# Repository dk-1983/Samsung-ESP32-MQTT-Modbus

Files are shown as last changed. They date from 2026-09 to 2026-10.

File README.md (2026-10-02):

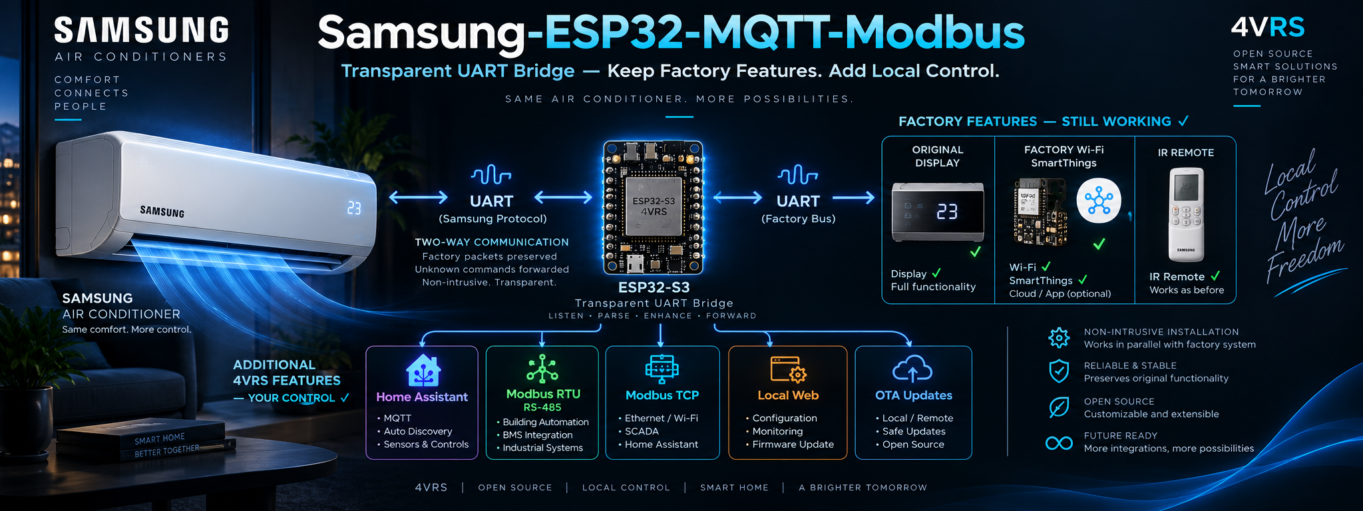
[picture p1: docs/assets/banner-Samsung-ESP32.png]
Samsung-ESP32-MQTT-Modbus — 4VRS


# Samsung-ESP32-MQTT-Modbus — 1.0.2

[Русский](README_RU.md)

**[Download stable v1.0.2](https://github.com/dk-1983/Samsung-ESP32-MQTT-Modbus/releases/tag/v1.0.2)** — ready-made OTA binary for already provisioned ESP32-S3 N16R8 controllers. Not a first-install image for a blank board.

**Keep Samsung's factory features and add 4VRS control.**

Samsung-ESP32-MQTT-Modbus is an ESP32-S3 expansion controller with a transparent
inline UART bridge between the AC motherboard and its original display/Wi-Fi board.
The architecture is designed to preserve the full factory functionality: the
original boards keep communicating, while the IR remote, display and Samsung
SmartThings coexist with the additional 4VRS interfaces.

Our 4VRS polling and command dispatcher runs on the ESP32. It tracks factory
transactions, selects an idle window for each own request and coordinates access
from the web controls, MQTT and Modbus to the shared UART bus. A command is confirmed
only by reading the actual AC state. Unknown factory packets are forwarded unchanged,
so forwarding is not limited to the commands implemented by our firmware.

Additional interfaces:

- **Wi-Fi:** local network connectivity and OTA firmware updates.
- **HTTP Remote:** a local web remote and HTTP API for control over the network.
- **MQTT / Home Assistant Discovery:** automatic device and entity discovery. No custom Samsung/4VRS integration, HACS package or manual entity configuration is required; use the standard MQTT integration with your broker.
- **Modbus RTU / TCP:** RS485 and network automation integration.

Local 4VRS interfaces do not require Samsung's cloud. Factory SmartThings retains
its own connection through the original Wi-Fi module. Display, IR remote and
SmartThings control have been checked with the bridge on AR24BSFCMWKNER;
exhaustive validation of every factory function is still pending.

Repository: [dk-1983/Samsung-ESP32-MQTT-Modbus](https://github.com/dk-1983/Samsung-ESP32-MQTT-Modbus).
See [bridge wiring and limitations](docs/UART_BRIDGE.md).

Home Assistant is optional: connect the controller to your own MQTT broker and automation server. See [topics, commands, states and the complete Discovery-based inventory](docs/HOME_ASSISTANT.md#own-mqtt-broker-without-home-assistant).

[Complete Modbus register list with Samsung / 4VRS separation](docs/MODBUS.md): the factory indoor-unit range ends at **2449**, and our extensions begin at **2450**.

[Electrical schematic, wiring and PCB component libraries](hardware/README.md).

## Home Assistant via Modbus Devices

**[Modbus Devices](https://github.com/dk-1983/Modbus_Devices#4vrs) includes a dedicated profile for this controller: manufacturer `4VRS`, model `Samsung-ESP32-Modbus`.**

Connect through Modbus TCP over Wi-Fi or Modbus RTU over RS485 to get climate
control, the full fan/swing/preset controls, confirmed writes, and link and command
diagnostics in Home Assistant. The profile uses our extended register map;
you do not need to enter each register manually. MQTT is not required for this option.

1. Install [Modbus Devices](https://github.com/dk-1983/Modbus_Devices#installation) in Home Assistant.
2. Open `/modbus` on the controller and enable TCP or RTU.
3. Add the device using **4VRS → Samsung-ESP32-Modbus** and your connection settings.
   For direct TCP, use the controller IP, port **502** and configured Unit ID (default **1**).
   For RTU, match the controller's serial settings (default **9600 8E1**).

Select the **4VRS** profile for this device; the Samsung **MIM-B19N(T)** profile
is for the factory adapter. For MQTT-based setup, use Home Assistant's standard
MQTT integration with Discovery as described above.

## Electrical schematic

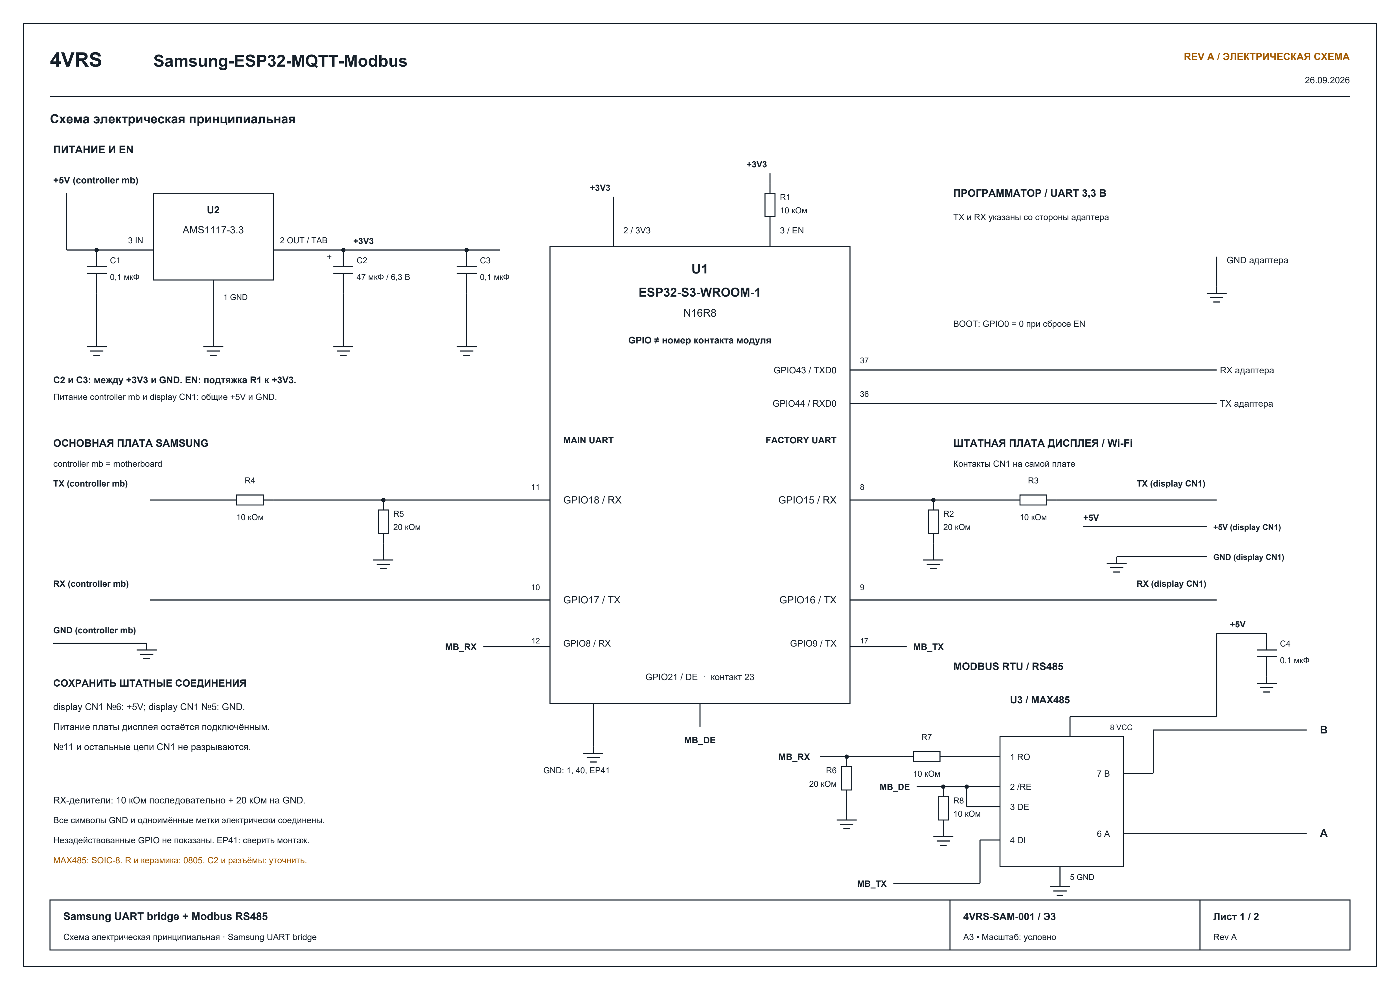
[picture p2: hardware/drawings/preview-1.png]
Samsung ESP32-S3 inline UART bridge and Modbus RS485 schematic


Motherboard UART: **RX18 / TX17**. Original display/Wi-Fi board: **RX15 / TX16**.
Modbus RS485: **RX8 / TX9 / DE21**. Numbers are ESP32 GPIOs, not module pad numbers.
Both Samsung boards retain their +5 V and common ground connections.

[Open full-resolution schematic](hardware/drawings/preview-1.png) · [Vector PDF](hardware/drawings/Samsung_transparency_bridge_revA-review.pdf) · [PCB component libraries](hardware/README.md)

## Controls and connections

The portal on port 80 links to controls, MQTT, Modbus and GitHub updates.
The Control link opens `/control`; advanced ESPHome controls remain on port 8080.
Both use `admin` and the same password stored on the device.

The main web interface on port 80 supports English and Russian. English is the
default; use the language selector to switch. Your browser remembers the selection.
This selector does not change the advanced ESPHome interface on port 8080.

- Independent persistent checkboxes for MQTT, Modbus RTU and Modbus TCP; all default off.
- Browser-configured MQTT broker/port/credentials/topic prefix and Home Assistant discovery.
- Browser-configured Modbus unit and RS485 baud rate; RTU defaults to 9600 8E1, TCP port 502.
- GitHub automatic-install checkbox, manual check/install, progress, signed manifest,
  board profile, SHA256 validation and rollback.
- Local ESPHome OTA remains available and is coordinated with the GitHub worker.

[Management and releases](docs/MANAGEMENT.md) · [Full device register map](docs/MODBUS.md)
· [Home Assistant MQTT Discovery](docs/HOME_ASSISTANT.md)
· [Modbus register reference (Russian)](docs/MODBUS_REGISTERS_RU.md)
· [UART function reference](docs/FUNCTIONS_RU.md)

UART TX/RX GPIO17/18 uses 9600 8N1. RS485 TX/RX/DE uses 9/8/21.
The AC uses D0 UART, not native Modbus; ESP32 implements the external register map.
Core addresses follow MIM-B19N/B19NT; custom functions begin at 2450.

UART is enabled on every boot and can be disabled in the control page.
Saving MQTT settings reboots the controller after two seconds to apply credentials.
Feedback is never optimistic: acknowledgement is not proof of the requested AC state.

## Hardware compatibility, first installation and updates

**Inline bridge support starts with firmware 0.5.0. Versions 0.4.x use the earlier
non-bridge configuration; 0.5.0 and later target the bridge wiring shown here.**
From the ESP32 side, the AC motherboard uses RX GPIO18 / TX GPIO17, the original
Wi-Fi/display board uses RX GPIO15 / TX GPIO16, and Modbus RS485 uses
RX GPIO8 / TX GPIO9 / DE GPIO21.
Module pads 8/9 are GPIO15/16 (the bridge), not GPIO8/9 (Modbus).

Boards wired for the pre-0.5.0 non-bridge configuration are a different hardware
configuration.
Do not install the current OTA on them solely because their firmware version is
older. Check the wiring against the current schematic first; an OTA update does
not add the missing bridge connection or change the PCB routing.

- **Configured controller with the current bridge wiring:** update through
  `/updates`. A working 1.0.0 or 1.0.1 installation on this hardware can update
  directly; no intermediate version is required. Preserve NVS when updating.
- **New controller with the current bridge wiring:** build the current stable
  source with `./Build.ps1`, personal `secrets.yaml` and `public_release: "false"`
  (the default). Use `firmware.factory.bin` for initial USB/serial installation.
  First boot saves the web, local OTA and Samsung-Setup passwords in NVS.
  Connect to Samsung-Setup with your setup password and configure Wi-Fi at
  `http://192.168.4.1:8080/`. Subsequent updates can use public OTA releases.

The public `*-ota.bin` requires existing device credentials in NVS; it is not a
first-install image for a blank board. A ready-made public provisioning image is
not provided yet. Installing an old firmware version first is not required.
Hardware compatibility and initial credential provisioning are separate requirements.

## Build and validation

Run `./Build.ps1` to install pinned dependencies, run host tests and build, without
flashing. Local configuration is in `secrets.yaml`; neither it nor locally built
private binaries belong in a public release. OTA/factory binaries are under
`work/build/.pioenvs/samsung-s3`. On the first local build boot, credentials are saved
to NVS and survive subsequent public OTA updates.

The separate GitHub workflow prepares a clean public **OTA-only** artifact for
controllers with the current bridge wiring and provisioned credentials. Signing/publishing is a separate step.
See [release preparation](docs/MANAGEMENT.md#release).

Power, fan Low/Medium/High/Turbo and both swing axes were tested on the target AC
in earlier firmware. Persistent web settings, Modbus TCP and GitHub OTA have
been checked on a device, including credential/settings retention and boot confirmation.
Authenticated MQTT connectivity is verified. Physical RS485 and forced rollback still need testing.
Experimental legacy controls require per-function verification on this model.

[Protocol](docs/PROTOCOL.md) · [Attribution](THIRD_PARTY.md)

The `/about` page shows firmware, memory, connections and UART freshness.
Restart requires confirmation and preserves settings. It is rejected during OTA
or while an AC command is pending.

`/settings` independently changes web, local OTA and Samsung-Setup passwords.
Blank fields preserve current credentials; new values require confirmation.
Changes are stored in NVS and applied on restart. Forgotten-password recovery
is not implemented yet.

`/wifi` shows network, IP, MAC, signal and channel. `/wifi/reset` confirms a
Wi-Fi-only reset; reprovision through Samsung-Setup at `192.168.4.1:8080`.
Other settings are preserved.

[Overview, web controls and MQTT power commands (Russian)](docs/CONTROL_RU.md).

HVAC commands require fresh control permission and feedback. Requested power is
never restored automatically after a restart.

In inline mode the factory board owns startup and notification ACKs. Own writes
require fresh permission and feedback, use an idle transaction window and are
confirmed by own readback, never by ACK alone. No automatic write retries.
Main RX18/TX17, factory RX15/TX16, RS485 RX8/TX9/DE21. All three hardware
UARTs are used; serial logging is disabled, web logging remains available.
Disabling UART transmission also stops factory forwarding.

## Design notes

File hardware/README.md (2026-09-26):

# Samsung transparency bridge — hardware, Rev A

**Рабочая принципиальная схема Samsung UART bridge и Modbus RS485.**

Здесь находятся электрическая принципиальная схема и база компонентов для PCB.
Это не законченная разводка печатной платы.

Контроллер включается между основной платой Samsung и штатной платой дисплея/Wi-Fi.
Прозрачный UART-мост предназначен для сохранения полного заводского функционала
с добавлением Wi-Fi, HTTP Remote, MQTT и Modbus RTU/TCP от 4VRS. Диспетчер очереди
опроса и команд на ESP32 согласует собственные запросы со штатным обменом.
Дисплей, ИК-пульт и SmartThings проверены на AR24BSFCMWKNER; это не означает
завершения проверки каждой заводской функции. Подробности — в README проекта.

## Электрическая схема

Схема, лист 1

- [PDF, два листа A3](drawings/Samsung_transparency_bridge_revA-review.pdf).
- [SVG, схема](drawings/Samsung_transparency_bridge_revA-sheet1.svg).
- [SVG, соединения и перечень элементов](drawings/Samsung_transparency_bridge_revA-sheet2.svg).

Первый лист содержит питание, ESP32 и два направления UART-моста, а также MAX485.
Второй разделяет номера GPIO, физические контакты ESP32 и контакты CN1 Samsung.
На чертеже не воспроизводится механическое расположение контактов разъёмов.

Соединения:

- C2, 47 мкФ / 6,3 В, подключён между +3V3 и GND, плюс к +3V3.
- C3, 0,1 мкФ, тоже подключён между +3V3 и GND, **не к EN**.
- EN подтянут к +3V3 через R1, 10 кОм.
- MAX485: SOIC-8. Резисторы и неполярные конденсаторы: 0805.
- Повторное обозначение R6 для подтяжки DE заменено на R8.
- Конденсаторам присвоены уникальные C1–C4; прежние рукописные номера не сохранялись.

## База для PCB

| Файл / каталог | Назначение |
|---|---|
| `components/BOM.csv` | 15 элементов, номиналы, символы и посадочные места |
| `components/components.json` | Та же база в структурированном виде |
| `components/connections.csv`, `nets.json` | 18 сетей и номера выводов компонентов |
| `components/external_connections.csv` | Соединение будущих разъёмов с CN1 и RS485 |
| `kicad/4vrs_Samsung.kicad_sym` | Шесть символов KiCad: ESP32, AMS1117, MAX485, R, C, CP |
| `kicad/4vrs_Samsung.pretty` | Пять официальных посадочных мест Espressif / KiCad |
| `kicad/sym-lib-table`, `fp-lib-table` | Локальные таблицы библиотек для проекта в `hardware/kicad` |
| `kicad/Samsung_bridge_review.net` | XML netlist для подготовки PCB, без невыбранных разъёмов |
| `tools/` | Исходники генераторов чертежа и базы |

Для нового проекта KiCad в каталоге `hardware/kicad` библиотеки используют
`${KIPRJMOD}`. При переносе проекта в другой каталог нужно изменить пути таблиц.
Файл `.kicad_sch` и разводка `.kicad_pcb` на этом этапе не создавались.
PDF/SVG редактируются через генератор, библиотеки — через KiCad.

Посадочные места сохранены без изменения из первоисточников. Ссылки и SHA-256
находятся в `kicad/footprint_sources.json`; лицензии — рядом с библиотеками.
3D-модели не копировались; ссылки в footprints могут требовать стандартных
3D-библиотек KiCad/Espressif. Это не влияет на геометрию контактных площадок.

## Что уточнить перед разводкой

1. Размеры и тип монтажа полярного C2. Его footprint намеренно не назначен.
2. Подтверждение корпуса AMS1117: в базе предложен SOT-223 с tab = OUT.
3. Серии, шаг, ориентация и число контактов собственных разъёмов платы.
   Контакты CN1 на чертеже — контакты кондиционера, не готовая распиновка PCB-разъёма.
4. Размер платы, монтажные отверстия, ориентация шлейфов и антенны модуля.
5. Допуски / мощность резисторов и рабочее напряжение керамических конденсаторов.

EP41 ESP32 включён в GND по документации модуля. GPIO35/36/37 в варианте
N16R8 зарезервированы под PSRAM и в библиотеке помечены как не подключаемые.
Добавлены линии программатора: GPIO43 (pad37) → RX адаптера, GPIO44 (pad36) ← TX адаптера, общий GND. Уровни адаптера: 3,3 В. Это три сигнальных соединения, не схема автоматического входа в загрузчик: для UART-загрузки нужен GPIO0 на GND во время сброса EN. Защита и терминатор RS485 пока не добавлены.

Ревизия чертежа: C4 напрямую соединён с +5V вывода 8 MAX485 и GND; R1 расположен непосредственно над EN (вывод 3 U1), без обходного провода; C2 и C3 подключены к общей линии +3V3 выхода стабилизатора. Одноимённые метки остальных сетей обозначают электрическое соединение.

## Проверки

PDF отрисован и просмотрен по листам. Генератор проверяет уникальность назначения
выводов сетям и наличие выводов в символах. Отдельно сверены наборы номеров pad
официальных footprints и символов. Проверена распиновка GPIO17/18, GPIO15/16,
GPIO9/8/21 относительно основной прошивки.

KiCad CLI в текущем окружении отсутствует: открытие библиотек / импорт netlist,
ERC и DRC в KiCad ещё не выполнялись. Отсутствие ошибок структурной проверки
не является подтверждением готовности к производству.

## Источники

- [Espressif ESP32-S3-WROOM-1 datasheet](https://www.espressif.com/sites/default/files/documentation/esp32-s3-wroom-1_wroom-1u_datasheet_en.pdf).
- [MAX485, Analog Devices](https://www.analog.com/en/products/max485.html).
- [AMS1117, документ производителя в архиве LCSC](https://datasheet.lcsc.com/lcsc/1811142212_Advanced-Monolithic-Systems-AMS1117-3-3_C6186.pdf).
- [Официальная библиотека Espressif](https://github.com/espressif/kicad-libraries).
- [Библиотеки KiCad: условия использования](https://www.kicad.org/libraries/license/).

Документация компонентов использована для обозначений выводов и посадочных мест.

Обозначения внешних цепей: `controller mb` — основная плата кондиционера (motherboard); `display CN1` — разъём платы дисплея. Обе платы подключены к общей линии +5V и GND. TX/RX обозначены относительно соответствующей платы.

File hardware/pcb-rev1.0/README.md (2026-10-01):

# Samsung UART bridge — PCB rev1.0

[Русский](README_RU.md)

30 × 48 mm (48 × 30 when rotated), two copper layers, 1.0 mm thickness in KiCad. Components on both sides, no mounting holes. Based on the Haier pcb-v1.1 circuit; the Haier project was not modified.

Files: samsung-rev1.0.kicad_pcb; review/samsung-both-sides.png (review only); circuit.json, connections.csv and BOM.csv; drc.json; review/pin-check.json; reproducible scripts in sources/.

KiCad DRC: 0 violations and 0 unconnected items. All 82 assigned logical pads match circuit.json. 25 U1/U2/U3 assignments independently match the Samsung schematic. This PCB has not been tested on hardware. Gerber and drill files are included in production/, together with an archive and a checksum manifest.

## Solder pads

MAIN and DISPLAY TX/RX labels refer to the external Samsung board, not the ESP.

- TP9–TP12 MAIN, left to right viewed from top: +5V, GND, motherboard TX through divider to GPIO18, motherboard RX from GPIO17.
- TP13–TP16 DISPLAY: +5V, GND, display TX through divider to GPIO15, display RX from GPIO16.
- TP7/TP8: RS485 A/B.
- TP1/TP2/TP3: programming TX0 GPIO43 / RX0 GPIO44 / GND.
- TP4/TP5/TP6 on bottom: EN / BOOT GPIO0 / 3V3 voltage monitor.

UART solder pads are 2 mm in diameter. No UART connectors. All power and grounds are common. Preserve factory Samsung connections outside the UART bridge.

RS485 uses GPIO8 RX, GPIO9 TX, GPIO21 DE and /RE. R6 10k pulls direction down. R7 120 ohm and solder jumper JP1 enable termination. All three RX inputs use 10k/20k dividers; ESP TX outputs are direct 3.3V.

## Assembly and references

PCB component numbering follows the Haier carrier and differs from the older Samsung revA PDF. Use this PCB's BOM.csv and connections.csv. Old Samsung resistor → PCB mapping: R1→R1, R2→R9, R3→R8, R4→R2, R5→R3, R6→R5, R7→R4, R8→R6. PCB R7 adds termination.

The Haier power circuit is retained: LM1117-3.3 SOT-223, 220uF and 100uF case-C capacitors and ceramic decoupling. This expands the old Samsung revA drawing, whose 47uF C2 package was unresolved. The regulator TAB and its thermal planes are +3V3, not GND. ESP ground planes and thermal vias remain separate. Both copper layers are clear beneath the antenna.

This PCB requires factory plated holes, unlike the homemade kitchen-hood PCB. Verify mechanical fit and the BOM against available components before ordering. No firmware, device or release changes were performed.

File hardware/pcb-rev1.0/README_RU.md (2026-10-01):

# Samsung UART bridge — PCB rev1.0

[English](README.md)

Плата 30 × 48 мм (тот же габарит 48 × 30 мм при повороте), 2 слоя, текущая толщина в KiCad 1,0 мм. Монтаж компонентов с обеих сторон. Без крепёжных отверстий. Основа — электрическая часть Haier pcb-v1.1; файлы Haier не изменены.

## Файлы

- samsung-rev1.0.kicad_pcb — разведённая плата для проверки.
- review/samsung-both-sides.png — обзор обеих сторон, не фотошаблон.
- circuit.json, connections.csv, BOM.csv — актуальные цепи и компоненты этой PCB.
- drc.json — отчёт KiCad; review/pin-check.json — сверка назначений.
- sources/ — воспроизводимые построение, трассировка, заливка, проверки и изображения.

DRC: 0 нарушений и 0 несоединённых цепей. 82 назначения выводов совпали с circuit.json; 25 назначений выводов U1/U2/U3 независимо сверены с исходной схемой Samsung. Аппаратные испытания этой платы не проводились. Gerber и файлы сверловки находятся в production/ вместе с архивом и манифестом контрольных сумм.

## Площадки

Все обозначения MAIN и DISPLAY TX/RX относятся к подключаемой плате Samsung, а не к ESP.

| Площадки | Назначение слева направо, вид сверху |
|---|---|
| TP9–TP12, MAIN | +5V, GND, TX основной платы → делитель → GPIO18; RX основной платы ← GPIO17 |
| TP13–TP16, DISPLAY | +5V, GND, TX дисплея → делитель → GPIO15; RX дисплея ← GPIO16 |
| TP7 / TP8 | RS485 A / B |
| TP1 / TP2 / TP3 | TX0 GPIO43 / RX0 GPIO44 / GND |
| TP4 / TP5 / TP6, снизу | EN / BOOT GPIO0 / 3V3 (контроль напряжения) |

Оба ряда UART — пятачки Ø2 мм, без разъёмов. Питание и GND общие. Штатные цепи Samsung вне UART-моста сохраняются.

RS485: GPIO8 RX, GPIO9 TX, GPIO21 DE и /RE. R6 10 кОм тянет направление к GND. R7 120 Ом и паяная перемычка JP1 включают терминатор A/B. На всех трёх входах RX стоят делители 10/20 кОм. TX выходы ESP прямые, 3,3 В.

## Монтаж и нумерация

Нумерация резисторов/конденсаторов унаследована от платы Haier и отличается от старого Samsung revA PDF. Для сборки использовать BOM.csv и connections.csv именно этой PCB. Соответствия резисторов старой схемы → PCB: R1→R1, R2→R9, R3→R8, R4→R2, R5→R3, R6→R5, R7→R4, R8→R6. Дополнительный R7 PCB — терминатор.

Сохранены обвязка питания исходной платы Haier, LM1117-3.3 SOT-223, ёмкости 220 мкФ и 100 мкФ case C и дополнительные керамические конденсаторы. Это расширенная обвязка относительно старой Samsung revA, где показан C2 47 мкФ без выбранного корпуса. TAB стабилизатора — +3V3; его теплоотводящие полигоны не соединены с GND. Полигоны GND и тепловые переходы ESP отдельные. Зона антенны свободна от меди обоих слоёв.

Плата рассчитана на заводскую металлизацию переходных отверстий, в отличие от самодельной платы вытяжки. Перед заказом проверить механическую посадку и актуальность BOM по имеющимся компонентам. Прошивка, устройства и релизы в этой работе не изменялись.

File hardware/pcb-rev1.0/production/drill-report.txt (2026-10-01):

Drill report for samsung-rev1.0.kicad_pcb
Created on 2026-10-01T17:26:23

Copper Layer Stackup:
    =============================================================
    L1 :  F.Cu                      front
    L2 :  B.Cu                      back

Drill file 'samsung-rev1.0-PTH.drl' contains
    plated through holes:
    =============================================================
    T1  0.300mm  0.0118"  (384 holes))
    T2  0.300mm  0.0118"  (12 holes))

    Total plated holes count 396

Drill file 'samsung-rev1.0-NPTH.drl' contains
    unplated through holes:
    =============================================================

    Total unplated holes count 0

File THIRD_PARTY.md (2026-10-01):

# Attribution

Samsung Wi-Fi UART protocol reference: https://github.com/kumy/esphome_samsung_ac,
commit 2b7c14002c7fe0b2d8bb24f4c8d245fe6888bc5b, GPL-3.0.
The firmware is provided under GPL-3.0-or-later; LICENSE contains GPL v3.

`components/samsung_uart/modbus_core.h` originated in the user's
Haier-ESP32+Modbus project. Copyright (c) 2026 Krivolap Dmitriy Aleksandrovich.
MIT notice retained in LICENSE-4VRS. The adapted transport uses the samsung_modbus
namespace and a Samsung-specific backend function-code allowlist.

ESPHome and its build dependencies retain their respective upstream licenses.

Extended register reference: https://github.com/kumy/samsung-ac, commit 7d9df9d8010fe11a8171ebbab044a74d56ee441d, GPL-3.0, proto/consts.go. Register names do not establish support on the target model.

Management pages, updater, JSON parser, certificates and version comparison derive from
Dmitriy’s Haier-ESP32+Modbus fourvrs_portal (MIT; underlying4VRS attribution in LICENSE-4VRS).
Samsung portal adapters are GPL-3.0-or-later. Public trust key belongs to the same publisher;
no private key or private configuration was copied. Banner supplied by the user.

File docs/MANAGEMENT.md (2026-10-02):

# Settings and GitHub OTA — Samsung-ESP32 1.0.2

[Русский](MANAGEMENT_RU.md)

## Portal language (1.0.1)

The port 80 portal defaults to English. Choose English / Русский in the navigation;
the browser stores a `samsung_ui_lang` cookie for one year (`Path=/`, `SameSite=Lax`).
A missing or unsupported value selects English. The preference applies to every
portal page, including Wi-Fi reset. Switching reloads the page and discards unsaved
form edits. It does not change controller settings or NVS and requires no device
restart. Clearing cookies or changing browsers or controller addresses restores
English. This selector does not control the advanced ESPHome UI on port 8080.

### Localization checks

Russian page templates remain the source. `components/samsung_portal/i18n/en.tsv`
maps their UI text to English. Run `python tools/build_ui_translations.py` after
editing a template or translation and include the generated `UiEnglish.h`.
`./Build.ps1 -TestOnly` checks catalog completeness, form contracts, all nine
language routes and the actual C++ page renderer, as well as protocol/bridge tests.

Browser checks use pinned Playwright from `tests/ui/package.json` and simulated
API responses, never a controller. After host tests, run:

```text
npm install --prefix tests/ui --ignore-scripts --no-package-lock
node tests/ui/node_modules/playwright/cli.js install chromium
node tests/ui/browser.cjs
```

The public build workflow runs these checks before compiling the OTA image.
Browser checks cover English/Russian, desktop/mobile layouts, cookie persistence,
forms, stale/offline feedback and confirmation dialogs. They do not certify a
firmware upload or device operation. Publish and verify the OTA asset before
updating the signed stable feed; never manually edit its signed payload.

## Local settings

### Wi-Fi (0.4.5)

`/wifi` shows SSID, IP, station MAC, RSSI in dBm, channel and setup AP status.
`/wifi/reset` separately confirms removal of only the saved network. Know the
Samsung-Setup password before resetting. Confirmation erases the network record
and restarts after two seconds; MQTT, Modbus, web/OTA/AP credentials and updater
settings are preserved. Join Samsung-Setup and open `http://192.168.4.1:8080/`
to provision a new 2.4 GHz network. Explicit reset does not restore the old network.
Ordinary connection loss starts the setup AP after roughly ten seconds without
erasing the saved network.

Authenticated GET `/wifi/status` never returns passwords. GET `/wifi/reset` is
read-only; POST requires authentication, CSRF `token` and `confirm=RESET_WIFI`.
It is blocked during OTA, pending restart or an AC command. Only the Wi-Fi NVS
record is erased, never all preferences. Configuration validation requires
captive provisioning without compiled station networks; the key layout must be
rechecked when upgrading the pinned ESPHome version.

Read-only operation and request guards are checked on the live bench. Actual
network deletion and reprovisioning require a separate test with setup AP access.

### Passwords (0.4.4)

`/settings` changes web authentication (`admin`, ports 80 and 8080), local OTA
and Samsung-Setup access point passwords independently. Each new password needs
confirmation; blank pairs preserve existing values. New web/OTA passwords accept
16–64 printable ASCII characters without spaces; AP passwords accept 8–63.
Existing web passwords of at least eight characters remain valid.

All fields are validated before a single NVS blob is written. Errors leave all
credentials unchanged. Actual changes restart the board after two seconds;
unchanged values cause neither a write nor a restart. Credentials survive OTA
and are never returned by the API. Sign in with the new web password after reboot.
Future local OTA uploads require the new OTA password; the computer's `secrets.yaml`
is not updated automatically.

Home Wi-Fi, MQTT and GitHub signature verification are unaffected. Changes are
blocked during OTA, scheduled restart or pending AC commands. Forgotten-password
recovery is not implemented; this page requires existing access.

Authenticated `GET /settings/config` returns only `credentials_ready`.
POST to the same endpoint requires CSRF `token` and matching pairs:
`web_password`/`web_confirm`, `ota_password`/`ota_confirm`,
`setup_password`/`setup_confirm`. Empty or omitted pairs preserve credentials.
Unknown/duplicate fields are rejected. Responses contain only `changed` and `restarting`.

### System information and restart (0.4.3)

`/about` shows firmware, hostname, IP, Wi-Fi station MAC, uptime, internal RAM,
PSRAM and Flash. Wi-Fi, MQTT, UART, AC freshness and enabled Modbus transports
are reported separately. The station MAC can be used for a DHCP reservation.

Restart requires confirmation and preserves settings. The page waits for a new
boot and reloads after reconnection. Restart is rejected during OTA or a pending
AC command. UART starts enabled. If the IP changes, reopen the page at its new address.

API: authenticated `GET /system/status` and `POST /system/restart`. POST also
requires the current CSRF `token` and `confirm=RESTART`; GET never restarts.
Diagnostics contain no passwords. `boot_id` changes on boot, `uptime_s` is uptime;
`storage_ok` reports storage initialization, not a continuous memory test.

Port80 hosts `/mqtt`, `/modbus`, `/updates`. Existing ESPHome controls/REST move to8080;
local ESPHome OTA remains3232. Modbus uses the0.3.0 map. Both web servers use the same
admin password. Initial private0.4.0 boot stores web/OTA/AP credentials from secrets.yaml
in NVS; later OTA images restore these values instead of their compiled defaults.

MQTT, RTU and TCP default off and have independent persistent checkboxes. Blank MQTT
password keeps the saved password; a separate checkbox clears it. Since 0.4.2 every MQTT settings save restarts the controller after two seconds
to recreate the MQTT client with the saved broker and credentials;
UART starts enabled. MQTT topics and discovery use ESPHome. Previously retained discovery messages are not removed when disabled.

Modbus changes apply immediately and close existing TCP clients. RTU uses8E1 with
9600/19200/38400/57600/115200 baud; unit1–247. Disabled RTU discards requests and disabled
TCP stops listening on502. Word2479 reports the transport flags. None enables AC UART.
Initial Wi-Fi configuration remains on the ESPHome captive portal at
`http://192.168.4.1:8080/` after joining Samsung-Setup; the port80 portal includes an AP link.

## Updates

Feed: `https://raw.githubusercontent.com/dk-1983/Samsung-ESP32-MQTT-Modbus/main/releases/stable.json`.
Profile: `samsung-s3-n16r8-v1`; assets must belong to Releases of that repository.
Automatic installation defaults on. Disabling it blocks installation but
allows checking. Checks start about one minute after boot and recur every6hours with
jitter. Network connectivity and synchronized clock are required.

The updater provides HTTPS verification, ECDSA P-256 manifest verification,
profile/size/SHA256/ESP32-S3 checks, separate app slot, trial boot confirmation and
rollback. A trial needs45seconds of healthy local services/network; failed restart or
timeout can select the previous slot. Samsung rollback has not yet been exercised.
The existing4vrs publisher public key is retained; no private key is copied. Distinct
Samsung profile/asset URLs reject manifests for other devices.

The worker waits for the main-loop flash handoff and pauses local OTA while writing.
Transport setting changes are rejected during updates, but disabling installation
remains available during download. GitHub OTA 0.4.0 → 0.4.1 passed on the device:
signed download, installation, preserved settings/credentials and trial boot confirmation.

## Release

1. For a blank board, install a local build of the current stable source with personal
   `secrets.yaml` and `public_release: "false"`; first boot saves credentials in NVS.
   Inline bridge support starts with 0.5.0; 0.4.x uses the earlier non-bridge
   configuration. Verify the GPIO wiring against the current schematic before
   updating hardware wired for a pre-0.5.0 firmware. On the current hardware, configured
   1.0.0/1.0.1 controllers can update directly. No old base firmware is required.
   Public OTA requires saved credentials and is not a first-install image.
2. Run `Prepare public OTA artifact` in GitHub Actions. Clean CI uses only
   `release.defaults.yaml`; packaging checks prevent local private binary publication.
3. Download and bench-test the artifact; install `requirements-release.txt`.
4. Sign with `python tools/sign_release.py --build <artifact-directory> --key <private-P256.pem> --out releases/stable.json`.
   The tool requires the key matching the firmware trust anchor.
5. Publish `v<version>` and its OTA asset, then the signed stable.json to main.

Stable release 1.0.2 provides a ready-made OTA binary and a signed stable update manifest. Public binaries require an already provisioned controller.

[Home Assistant MQTT Discovery setup and validation status](HOME_ASSISTANT.md).

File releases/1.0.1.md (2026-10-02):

# Samsung-ESP32-MQTT-Modbus 1.0.1

The main web portal now opens in English by default. Select English or Russian
from the navigation on any portal page; the browser remembers the selection for
one year at that controller address. Switching languages reloads the page, so
save form edits first. No controller restart is needed.

Both languages cover the overview, AC controls, MQTT, Modbus, Wi-Fi, Wi-Fi reset,
passwords, updates and system information. Russian remains available. API fields,
MQTT topics, Modbus registers and AC command confirmation are unchanged.

This release retains the startup status-read fix from 1.0.0. The language selector
applies to the main portal on port 80; the advanced ESPHome UI on port 8080 is
unchanged. Clearing cookies or using another browser/address restores English.

## Installation

Use the signed OTA image only on an already provisioned ESP32-S3-WROOM-1 N16R8
controller. This is not a factory image for a blank board. Existing credentials
and persistent transport settings are retained by the OTA update.

## Validation and limitations

The release checks include host protocol/bridge tests, generated-translation and
page-rendering checks, browser tests with simulated API responses in both languages,
and firmware compilation. Simulated browser tests do not replace device testing.
Physical RS485, forced rollback and unverified legacy AC functions retain their
existing validation limitations.

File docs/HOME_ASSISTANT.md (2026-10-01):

# Home Assistant through MQTT Discovery

[Русский](HOME_ASSISTANT_RU.md)

Samsung-ESP32 publishes MQTT Discovery through ESPHome. No custom Samsung integration,
Hub, HACS package or manually configured YAML entities are required.

## Setup

1. Add the standard MQTT integration under Home Assistant Settings → Devices & services.
2. Open `http://<controller-IP>/mqtt`. Enter the same broker, port (usually 1883),
   username and password. Enable MQTT and Home Assistant Discovery.
3. Save. Firmware 0.4.2 reboots after two seconds to apply the connection settings.
   An empty password preserves the saved value; a separate checkbox clears it.
   The saved password is never returned to the browser.
4. Wait for connection. **Samsung-ESP32-MQTT-Modbus** appears under MQTT with
   **Air conditioner**, settings and diagnostic entities.
5. UART starts enabled on every 0.4.2 boot. The **UART transmission experimental**
   switch in web controls can disable it. **AC feedback fresh** reports UART freshness.

If discovery fails, check authentication, matching broker addresses, publish/subscribe
permissions and the `homeassistant` discovery prefix. Saving does not prove connection.

## Topics and availability

- Discovery: `homeassistant/<type>/samsung-s3/<entity>/config`. Unique IDs use the
  controller MAC address; entities share a device entry.
- Operational prefix defaults to `samsung-s3` and is configurable. Read individual
  command and state topics from the discovery payloads.
- Retained configurations are delivered when HA connects. There is no separate
  `homeassistant/status` handler in the current firmware.
- MQTT availability represents controller connectivity. **AC feedback fresh**
  separately reports UART freshness; broker connection does not prove AC connectivity.
- Disabling discovery does not remove configurations already retained by the broker.

Authenticated MQTT, reconnection after reboot and incoming data have been checked
on the bench. Experimental functions still require hardware validation. Requested
values are not published as observed AC feedback.

[Home Assistant MQTT documentation](https://www.home-assistant.io/integrations/mqtt/).

## Own MQTT broker without Home Assistant

Connect the controller to an independent MQTT broker using `/mqtt`: configure the host,
port, credentials and topic prefix. Home Assistant is not required; your own server,
Node-RED or another automation client can publish commands and consume feedback.

MQTT uses topics and message payloads, not Modbus register addresses. To obtain the
interface inventory for the installed firmware, enable MQTT and Discovery, subscribe
to `homeassistant/#` and identify the device configurations by MAC / `device`.
Discovery publishing does not require a running Home Assistant instance. Read command
and state topics, supported values, templates and availability from the configuration
JSON; field names may be abbreviated. Subscribe to `<prefix>/#` to observe operational
messages (default `samsung-s3/#`). Use the actual topics advertised by Discovery.

These retained configurations form a machine-readable entity inventory. Discovery
can be disabled after setting up your client while operational MQTT remains enabled;
disabling Discovery does not erase previously retained configurations.

| Action | Topic with default prefix | Payload |
|---|---|---|
| Power on | `samsung-s3/button/ac_power_on/command` | `PRESS` |
| Power off | `samsung-s3/button/ac_power_off/command` | `PRESS` |

Send commands without retain and confirm execution from AC feedback. Publishing a
message or receiving a broker acknowledgement does not prove AC execution.

[Power commands and HTTP API (Russian)](CONTROL_RU.md) ·
[UART function catalog (Russian)](FUNCTIONS_RU.md) · [Separate Modbus register map](MODBUS.md).

## Raw UART logging (0.5.1)

Raw frames are published in full to dedicated MQTT topics, without Home Assistant
Discovery entities and without retain:

| Topic | Payload |
|---|---|
| `<prefix>/diagnostics/uart/rx` | Latest received frame, complete space-separated HEX |
| `<prefix>/diagnostics/uart/tx` | Latest transmitted frame, complete space-separated HEX |
| `<prefix>/diagnostics/uart/write_reply` | Latest write reply, complete space-separated HEX |

Subscribe to `<prefix>/diagnostics/uart/#` with your logging client. The configured
prefix is used, including custom prefixes. RX/TX snapshots update every 2 seconds;
write-reply snapshots every second. These are latest-frame diagnostics, not a
lossless bus capture: intermediate frames can be superseded and MQTT disconnections
are not buffered. Full frames also remain in local diagnostics and web logs.

Firmware removes the three old retained Discovery configurations and state messages
on MQTT connection. Climate controls, decoded values and other diagnostic entities
remain available in Home Assistant. Manually configured raw-frame sensors must be
removed manually. Home Assistant's 255-character entity state limit no longer
applies to these logging topics because they are not advertised as entities.

## Startup and recovery logging (0.5.2)

The controller publishes non-retained JSON events to `<prefix>/diagnostics/boot`
with QoS 1: `boot_ready`, `mqtt_reconnected`, and `ac_connection_restored`.
Fields: `version`, `boot_id` (same across MQTT reconnects), `uptime_s`,
`controller_ready`, `boot_confirmed`, and `ac_ready`.

`boot_ready` requires Wi-Fi, MQTT, the web server, healthy settings/credential
storage, an available update service, and confirmed firmware boot. Conditions
must remain healthy for 5 seconds. After OTA, boot confirmation first requires
45 seconds of local health checks. It does not wait indefinitely for AC feedback:
`ac_ready: false` explicitly means the controller is ready but AC communication
is not. A subsequent stable AC recovery produces `ac_connection_restored`.
AC power-off is not itself a communication failure.

Use the [example automation](../examples/home-assistant-boot-log.yaml) in a new
Home Assistant automation's YAML editor, replacing `samsung-s3` with your MQTT
prefix. Merge this into `configuration.yaml` (do not duplicate an existing logger):

```yaml
logger:
  logs:
    samsung_controller: info
```

Reload/restart Home Assistant as required for the logger configuration. The automation
writes successful startup/recovery to `system_log.write` at INFO. INFO appears in
full logs, not the condensed warnings/errors list. Events are not retained, so
restarting Home Assistant does not replay a previous boot. An offline subscriber
can miss events; QoS 1 can deliver duplicates. These messages supplement MQTT
availability and AC freshness; they do not suppress unrelated integration warnings.

[Home Assistant System Log](https://www.home-assistant.io/integrations/system_log/).

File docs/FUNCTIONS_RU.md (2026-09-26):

# Справочник функций UART

Цель: Samsung AR24BSFCMWKNER, прямой UART штатного Wi-Fi-модуля, 9600 8N1.
Это реализация найденной карты команд, а не заявление о поддержке всех функций модели.
Полной официальной карты этого интерфейса у нас нет. Значения legacy взяты из
[kumy/samsung-ac](https://github.com/kumy/samsung-ac/blob/7d9df9d8010fe11a8171ebbab044a74d56ee441d/proto/consts.go).

## Основные команды

Веб-климат и MQTT climate предоставляют питание, пять рабочих режимов, температуру
16–30 °C, вентилятор Auto/Low/Medium/High/Turbo, качание Off/Vertical/Horizontal/Both.
В режиме Fan температура не регулируется самим кондиционером.

Preset: None, Boost, Sleep; custom preset: quiet, legacy_smart, legacy_soft_cool,
legacy_wind_1, legacy_wind_2, legacy_wind_3. Последние названия сохранены по исходному
протоколу: это НЕ подтверждённое соответствие современным AI/Eco/WindFree.

Modbus теперь использует [карту MIM-B19N/B19NT](MODBUS.md): питание 52, режим 53,
скорость 54, вертикальное качание 55, температура 58 (×10). Полное качание — 2484,
preset — 2485, полный набор скоростей с Turbo — 2486, Quiet — 2487.
Адреса PDU начинаются с нуля. Старые адреса версии 0.2.0 удалены.

## Расширенные команды

Веб-select/number/button автоматически доступны и через стандартные сущности MQTT ESPHome.
Все записи требуют включённого UART и свежего основного состояния (<10 с).
Новый регистр разрешено испытать без его предварительного успешного чтения: иначе невозможно
исследовать функции, которые начинают возвращать состояние только после первой записи.
В каждый момент разрешена только одна основная либо расширенная команда.

| Индекс | Функция | Группа/регистр | Запись holding | Значения на проводе |
|---|---|---|---:|---|
| 0 | Sleep flag legacy | 12/73 | 2450 | 00 включить, FF выключить; не таймер в часах |
| 1 | Auto clean | 13/32 | 2451 | 22 включить, 23 выключить |
| 2 | Ionizer SPI legacy | 13/75 | 2452 | 0F включить, F0 выключить; наличие ионизатора не предполагается |
| 3 | Energy setting raw legacy | 13/40 | 2453 | 0–255, единицы и применение на нашей модели неизвестны |
| 4 | Reset filter reminder | 13/44 | 2454 | 00, однократное действие |
| 5 | Filter interval legacy | 14/E9 | 2455 | 00/01/02/03/04: upstream 0/180/300/500/700; единицы не подтверждены |
| 6 | Reset usage counters | 14/E8 | 2456 | 01, однократное действие |
| 24 | Airflow direction legacy | 12/63 | 2474 | 12 Legacy off (not accepted on target); 21 Indirect; 31 Direct; 41 Center; 51 Wide; 61 Left; 71 Right; 81 Long; 82 legacy vertical; 92 Vertical; A2 Horizontal; B2 Both; C2 Fixed |

Числа в колонке значений — HEX, кроме явно указанного диапазона 0–255.
Legacy direction не задаёт угол в градусах. 82 конфликтует с подтверждённым на нашем
блоке вертикальным качанием 92, поэтому вынесено отдельно. Если ответ содержит неизвестный
код направления, основное поле swing становится неизвестным; восстановить известный вариант
можно через select Airflow direction legacy или holding 2474, например B2=178.

## Диагностические чтения

Кнопка Read extended Samsung status однократно запрашивает 25 регистров по одному.
Локальный переключатель Extended status polling включает их циклический опрос.
Это только чтение: сбросы, служебные настройки, режимы и Wi-Fi этим не изменяются.
Значения представлены как исходные байты HEX, без выдуманных единиц и кодов ошибок.
Текст `unknown` означает отсутствие ответа, `stale raw ...` — ответ старше 30 секунд.
FC/FE/FF в значении сохраняются буквально; они не объявляются универсальным кодом ошибки.

| Индекс | Поле | Группа/ID |
|---|---|---|
| 7 | Beep raw | 12/74 |
| 8 | Error bytes | 12/F7 |
| 9 | Outdoor temperature raw | 13/76 |
| 10/11 | Cooling/Heating capability raw | 13/77, 13/78 |
| 12 | Power raw | 14/32 |
| 13 | Energy raw | 14/E0 |
| 14 | Runtime raw | 14/E4 |
| 15 | Filter usage raw | 14/E6 |
| 16/17/18 | Main/Panel/Outdoor version | 14/F6, 14/F4, 14/F3 |
| 19 | Model code | 14/F5 |
| 20 | Option code (только чтение) | 14/39 |
| 21 | Control enable | 12/01 |
| 22/23 | WiFi/Internet status raw | 14/37, 14/38 |

Включая управляющие поля 0–6 и 24, это весь каталог 0–24.
Modbus holding 2450+индекс читает однобайтовое значение; многобайтовое/неизвестное/устаревшее
значение возвращает exception 0B. Запись в read-only возвращает 02, неверное значение — 03,
занято/monitor — 06. Расширенная запись допускается только одиночная; смешанные пакеты
и несколько расширенных записей отвергаются целиком до отправки UART.

Input 2481: результат расширенной команды; 2482: индекс последней (255 если нет); 2483: размер каталога (25).
Для каждого индекса есть блок input `2500 + 18*индекс`: слово 0 = длина (1–32),
слова 1–16 = байты попарно big-endian, дополненные нулями; слово 17 = возраст в секундах
(65535 неизвестно). Сырые блоки протухают через 30 с и возвращают 0B, возраст читается всегда.

## Подтверждение и ограничения

Основной Command result и Extended command result разделены. Коды:
0 idle, 1 pending, 2 confirmed, 3 timeout_unconfirmed, 4 cancelled;
для расширенных одноразовых действий 5 acknowledged_unverified.

1205/1305/1405 — ответы на запись: они НЕ обновляют состояние. Для обычной команды
нужно совпавшее последующее чтение/уведомление. Для сброса счётчика даже точное эхо
помечается acknowledged_unverified: факт сброса нужно сверить отдельным чтением счётчика.
Last write reply сохраняет полный ответ для анализа.

UART включён после загрузки. В режиме моста инициализацию и подтверждение
уведомлений выполняет заводская плата; контроллер пересылает их без дублирования.
Для локальных команд нужны свежие разрешение управления и обратная связь.
Отклонённые команды не повторяются автоматически. Служебные кадры не используются
как состояние климата. См. [описание моста](UART_BRIDGE_RU.md).

## Пока не расшифровано

Не добавлены выдуманные команды Display, WindFree, Eco, AI, таймер включения/выключения,
углы жалюзи в градусах, блокировка ИК-пульта, переключатель Beep. Для их реализации нужен
подтверждённый пакет или источник для этого UART-профиля. Эти функции не подменяются
похожими названиями из старого протокола либо регистрами NASA/RS485.

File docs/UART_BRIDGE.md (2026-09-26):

# Inline UART bridge and 4VRS dispatcher

[Русский](UART_BRIDGE_RU.md)

The ESP32 sits between the Samsung motherboard and the original display/Wi-Fi
board. Factory traffic is forwarded while local web, MQTT and Modbus control
share the 4VRS polling and command dispatcher.

## Wiring

| Connection | ESP32 GPIO | Module pad |
|---|---|---|
| Motherboard TX → ESP32 RX, through level conversion | 18 | 11 |
| ESP32 TX → motherboard RX | 17 | 10 |
| Display CN1 TX → ESP32 RX, through level conversion | 15 | 8 |
| ESP32 TX → display CN1 RX | 16 | 9 |
| Modbus receiver RO → ESP32 RX, through level conversion | 8 | 12 |
| ESP32 TX → Modbus DI | 9 | 17 |
| Modbus DE and /RE | 21 | 23 |

Retain display-board +5 V, common ground and other original connections.
TX/RX labels refer to the respective device. Follow the
[electrical schematic](../hardware/README.md); do not join TX outputs.
Both Samsung UARTs use 9600 8N1. Modbus RTU defaults to 9600 8E1.

## Factory functionality

The bridge is designed to preserve factory functionality, including the display,
IR remote and Samsung SmartThings, while adding local 4VRS interfaces. These
three factory functions have been checked on AR24BSFCMWKNER; every possible
factory feature and other AC models have not been exhaustively validated.
Unknown or damaged factory data is forwarded unchanged. Frame buffering can
introduce latency; the bridge does not guarantee original inter-byte timing.

## Polling and command dispatch

The dispatcher tracks factory transactions and inserts own requests in an idle
window. During an own transaction, factory requests can be held in a bounded
queue; notifications and acknowledgements continue through the bridge.
Local commands require current feedback, control permission and an available
transaction window. Busy commands are rejected, not queued for later execution.

Own replies are separated from factory traffic by envelope, group, response type
and counter. A command is confirmed by own readback of the requested state;
a write acknowledgement alone is not sufficient. No automatic write retries occur.
Factory notifications continue updating the displayed AC state.

Factory initialization and notification acknowledgements remain the responsibility
of the original board. The ESP32 does not duplicate them in inline mode.

## Diagnostics and availability

Use About and `/system/status` for `inline_bridge` and bridge diagnostics:
traffic counts, pending transactions, queue use, parse errors, timeouts and UART
configuration. Three hardware UARTs are used; logs are available through the web.

UART forwarding starts enabled after boot. Disabling UART transmission stops
both local commands and factory forwarding, discarding pending queues. It does
not record traffic for later replay. There is no hardware bypass: loss of ESP32
power or stopped forwarding interrupts communication between the factory boards.

Very late replies after transaction-counter reuse remain a protocol limitation.
Physical RS485 and forced OTA rollback still require validation.

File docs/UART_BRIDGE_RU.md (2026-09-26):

# Прозрачный UART-мост и диспетчер 4VRS

[English](UART_BRIDGE.md)

ESP32 включается между основной платой Samsung и штатной платой дисплея/Wi-Fi.
Заводской обмен пересылается через мост, а локальный веб-пульт, MQTT и Modbus
используют общий диспетчер опроса и команд 4VRS.

## Подключение

| Соединение | GPIO ESP32 | Контакт модуля |
|---|---|---|
| TX основной платы → RX ESP32 через согласование уровней | 18 | 11 |
| TX ESP32 → RX основной платы | 17 | 10 |
| TX display CN1 → RX ESP32 через согласование уровней | 15 | 8 |
| TX ESP32 → RX display CN1 | 16 | 9 |
| RO приёмника Modbus → RX ESP32 через согласование уровней | 8 | 12 |
| TX ESP32 → DI Modbus | 9 | 17 |
| DE и /RE Modbus | 21 | 23 |

Сохраните +5 В платы дисплея, общую землю и остальные заводские соединения.
TX/RX обозначены относительно соответствующего устройства. Следуйте
[принципиальной схеме](../hardware/README.md); не объединяйте выходы TX.
Оба UART Samsung работают на 9600 8N1. Modbus RTU по умолчанию — 9600 8E1.

## Заводской функционал

Мост предназначен для сохранения заводского функционала, включая дисплей,
ИК-пульт и Samsung SmartThings, с добавлением локальных интерфейсов 4VRS.
Эти три функции проверены на AR24BSFCMWKNER; исчерпывающая проверка всех
заводских возможностей и других моделей кондиционеров ещё не выполнена.
Неизвестные или повреждённые заводские данные пересылаются без изменения.
Буферизация кадров может добавлять задержки; сохранение исходных межбайтовых
интервалов не гарантируется.

## Опрос и отправка команд

Диспетчер отслеживает заводские транзакции и отправляет собственные запросы
в свободное окно. Во время собственной транзакции заводские запросы могут
временно помещаться в ограниченную очередь; уведомления и подтверждения
продолжают проходить через мост.
Для локальной команды нужны свежая обратная связь, разрешение управления
и доступное окно передачи. При занятости команда отклоняется, а не ставится
в очередь для отложенного исполнения.

Собственные ответы отделяются от заводского обмена по заголовку, группе,
типу ответа и счётчику. Команда подтверждается собственным чтением фактического
состояния; одного ACK записи недостаточно. Автоматических повторов записи нет.
Заводские уведомления продолжают обновлять отображаемое состояние кондиционера.

Инициализацию и подтверждение заводских уведомлений выполняет штатная плата.
В режиме моста ESP32 не дублирует эти действия.

## Диагностика и доступность

На странице «О системе» и в `/system/status` доступны `inline_bridge` и
диагностика моста: счётчики обмена, ожидающие транзакции, использование очереди,
ошибки разбора, тайм-ауты и параметры UART. Заняты три аппаратных UART;
журнал доступен через веб-интерфейс.

После загрузки пересылка включена. Отключение передачи UART останавливает
и собственные команды, и заводскую пересылку, очищая ожидающие очереди.
Данные не записываются для последующего воспроизведения. Аппаратного обхода нет:
отключение питания ESP32 или остановка пересылки прерывает связь заводских плат.

Очень поздние ответы после повторного использования счётчика транзакции
остаются ограничением протокола. Физический RS485 и принудительный откат OTA
ещё требуют проверки.

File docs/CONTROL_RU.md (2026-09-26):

# Обзор, веб-пульт и команды питания — 0.4.6

Главная страница `/` показывает температуру помещения, уставку, питание, режим
и отдельные состояния контроллера, UART, связи с кондиционером и MQTT.
`/control` добавляет температуру, режим, скорость включая Turbo, оба качания
и пресеты. Экспериментальные функции и сырые ответы доступны по ссылке
«Открыть расширенный пульт» на порту 8080.

## Питание

Кнопки «Включить» и «Выключить» отправляют только поле питания Samsung UART.
Режим, температура, скорость, качание и пресет не включаются в эту команду.
Включение не выбирает охлаждение или другой режим. Выбор режима в новом веб-пульте
также не меняет питание: это отдельные действия.

Значения на странице берутся из обратной связи, не из отправленной команды.
HTTP 202 означает принятие к отправке, а не подтверждение исполнения. Показатель
«Последняя команда контроллера» отображает pending / confirmed / timeout / cancelled;
он общий для всех источников управления, включая MQTT и Modbus.
Неизвестное или устаревшее поле отображается как «—». При потере HTTP-связи
кнопки блокируются. Кнопки также недоступны при выключенном UART, устаревшем
CORE, обновлении или ожидающей команде. Сервер повторно проверяет условия записи.

## MQTT

В Home Assistant MQTT Discovery добавлены две кнопки: **AC power on** и
**AC power off**. Это команды без собственного состояния. Фактическое состояние
по-прежнему читается из climate и диагностики **AC feedback fresh**.
Так при загрузке не публикуется выдуманное состояние питания новой сущности.

Топики при стандартном префиксе:

| Команда | Topic | Payload |
|---|---|---|
| Включить | `samsung-s3/button/ac_power_on/command` | `PRESS` |
| Выключить | `samsung-s3/button/ac_power_off/command` | `PRESS` |

При изменении префикса заменить `samsung-s3` на настроенное значение.
Точные топики также содержатся в Discovery. Отправлять **без retain**.
Кнопки используют штатный ESPHome MQTT, который не фильтрует retained-команды:
сохранённое брокером сообщение может повториться после переподключения.
Отдельного автоматического восстановления состояния питания в обработчиках нет.
Не использовать retained-команды для управления кондиционером.

Веб и MQTT вызывают общий `set_power(bool)`, который формирует единственное
поле `POWER` и использует существующую проверку свежести, занятости и UART.
Отказ MQTT-команды записывается в журнал; нажатие кнопки HA не является
подтверждением изменения питания. Старое управление через MQTT climate сохраняется.

## HTTP API

- `GET /control/status`: авторизованный JSON, неизвестные поля = null;
  `power`, `target`, `mode`, `fan`, `swing`, `preset`, `room`, состояния связи,
  `busy`, `can_command`, результаты команд.
- `POST /control/set`: авторизация, текущий CSRF `token`, `field`, `value`.
  Один параметр за запрос. `field=power`, `value=1` включает; `value=0` выключает.
  Поля target/mode/fan/swing/preset принимают нормализованные UART-значения
  (не заводские коды Modbus): target 16..30, mode 1 cool / 2 heat / 3 dry /
  4 fan / 5 auto; fan 1 low / 2 medium / 3 high / 4 auto / 5 turbo;
  swing 0 off / 1 vertical / 2 horizontal / 3 both; preset 0..8.
- Ошибки: 400 — неверное поле/значение, 401 — нет авторизации,
  403 — неверный token, 409 — сейчас нельзя отправить команду.

## UART-мост (0.5.0)

Веб, MQTT и Modbus используют тот же общий submit/set_power. Подтверждение
команды теперь требует собственного ответа чтения, а штатные уведомления
обновляют отображаемое состояние. Ответ busy возможен также при незавершённой
штатной транзакции; отклонённая команда не ставится в очередь и не повторяется.
Страница About содержит диагностическую строку моста и скорости всех трёх UART.

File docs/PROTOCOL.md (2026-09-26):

# Experimental Wi-Fi UART D0 profile

Target electrical layer: direct Wi-Fi-module UART, configured **9600 8N1**.
This is distinct from NASA RS485 **9600 8E1** (32…34). No automatic protocol detection/transmit fallback.
Core control verified on AR24BSFCMWKNER. See hardware/README.md for level conversion.

Frame: `D0 C0 02 LEN 00 00 00 00 00 COUNTER FE TYPE_H TYPE_L PAYLOAD_LEN [ID LEN VALUE...] XOR E0`.
Total length = LEN+4 = PAYLOAD_LEN+16. LEN is one byte, so payload maximum 243 bytes.
Checksum is XOR of all bytes before checksum/footer. Lengths, header, footer, checksum and TLV boundaries
are validated before interpretation. Parser is bounded to 259 bytes; incomplete frames expire after 200 ms.
Unknown register IDs are skipped, unknown enum values invalidate that field instead of guessing.

Types: 1202 read, 1203 read response, 1204 write, 1205 write response, 1206 notification, 1207 notification ACK.
Only 1203/1206 update state. Notifications receive ACK only in active mode, with the received counter and payload.
ACK counter semantics still need confirmation on hardware. No automatic HVAC command retries; max 4 queued ACKs.
Minimum TX interval 300 ms, minimum RX quiet interval 30 ms, status query every 5 s.
Since 0.4.7, each core poll also reads register 01. A fresh F0 triggers 1204
with `01 01 0F` only, at most once per 30 seconds. Writes are gated until a
1203/1206 readback reports 0F (expires after 15 seconds). A write ACK is not proof.
Automatic recovery does not change beep, power, mode or replay failed commands.
All recovery traffic respects the local UART disable switch and bus idle checks.
The optional manual initialization still writes `01 01 0F 74 01 F0`.

| ID | Meaning | Known values |
|---|---|---|
| 02 | Power | 0F on / F0 off |
| 43 | Mode | 12 cool / 22 dry / 32 fan / 42 heat / E2 auto |
| 5A | Target | whole °C, firmware permits 16–30 |
| 5C | Room | signed whole °C |
| 62 | Fan | 00 auto / 12 low / 14 medium / 16 high / 18 turbo |
| 63 | Swing | C2 stop (verified target); 12 legacy stop read / 92 vertical / A2 horizontal / B2 both |
| 44 | Preset | 12 none / 22 boost / 42 sleep / 52 quiet |

Version 0.2.0 adds legacy presets 32/62/82/92/A2 and an explicit experimental direction selector; see FUNCTIONS_RU.md.
No WindFree assumption. F7 error payload is preserved as raw Samsung bytes.

The first valid state can be collected passively. A command requires fresh core data (power, mode,
temperature and fan) and fresh data for every requested field. Confirmation requires all requested fields
to be observed matching after the transmission; an ACK or unrelated notification cannot confirm a command.
This is observed feedback, not a proven transaction identifier match. Hardware may require additional
handshake/registration messages, a different checksum/profile, or different register enums.

Sources:
- [kumy/esphome_samsung_ac](https://github.com/kumy/esphome_samsung_ac), inspected commit
  `2b7c14002c7fe0b2d8bb24f4c8d245fe6888bc5b`, including protocol tests.
- [Foxhill67/esphome_samsung_ac](https://github.com/Foxhill67/esphome_samsung_ac), different bus family;
  not used as the direct Wi-Fi UART driver.

The checksum condition and unchecked parsing in the referenced Wi-Fi implementation were not reused.
The implementation uses strict equality and bounded parsing, with independent regression tests.

## Extended profile 0.2.0

`extended.h` contains a bounded allowlist of 25 register definitions from kumy/samsung-ac,
commit `7d9df9d8010fe11a8171ebbab044a74d56ee441d`. Groups 12/13/14 share read/write/notify
suffixes 02/03/04/05/06/07. Read responses/notifications alone update raw state.
One pending command is shared across core and extended interfaces; a rejected write has no UART side effects.
Extended ordinary writes confirm only matching subsequent feedback; action ACKs are explicitly unverified.
Raw values expire after 30 seconds; no guessed physical units or universal sentinel meanings.
The observed FC envelope is structurally validated and counted separately; never interpreted as FE climate
feedback and never acknowledged without a protocol reference. See FUNCTIONS_RU.md for the exact catalogue.

## Inline operation (0.5.0)

The optional factory UART changes ownership: original notifications/ACKs and
startup frames are forwarded, not regenerated. Automatic permission recovery
and manual legacy initialization are disabled in inline mode. Commands require
fresh 01=0F feedback. Own reads and writes share a dispatcher with the factory
traffic; their replies are isolated by FE envelope, group, reply type and counter.
Core commands are confirmed only by own read responses after transmission;
forwarded notifications still update displayed state. No write retry is automatic.
The direct, single-UART profile retains the older behavior described above.

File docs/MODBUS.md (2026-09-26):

# 4vrs → Samsung-ESP32 — complete device Modbus map 0.3.0

Source: Samsung DB68-07538A-03, pages 8–10 and 13–18.
[Official manual](https://images.samsung.com/is/content/samsung/assets/es/docs/subcarpeta-1/IM-MIM-B19N-DB68-07538A-03_IM_Modbus_Interface_Module_GB_EN_221130-D01.pdf).
Local original: `reference/Samsung-MIM-B19N-B19NT-official-manual.pdf`.

This is the complete map of **our Samsung-ESP32 device**, intended for its own
Home Assistant Modbus Devices definition under **4vrs → Samsung-ESP32**.
MIM-B19N provides the address and value conventions for matching functions;
it does not limit the UART features exposed by our product. The ESP32 translates
Modbus to the existing D0 Wi-Fi UART profile.
All addresses below are decimal **zero-based PDU addresses**. IU0 is fixed; it is
independent of Modbus unit ID (default 1). The factory indoor formula is
`50 + 50*IU + offset`, IU 0–47. Thus IU0 occupies 50–99 and IU47 ends at 2449.
Keep unused factory addresses reserved, including extension slots 82–99 and
factory MessageSet configuration at 6000/7000.

RTU: **9600 8E1**, GPIO9 TX / GPIO8 RX / GPIO21 DE, active high.
TCP: port 502. FC03/04 read; FC06/16 write. Coils and FC01/05/15 are removed (01).
Both read functions expose the same readable words in this implementation.
FC16 accepts up to 8 words, validates the entire request before submitting one
UART command, and rejects mixed core/extended or multiple extended writes (03).
Positive response means accepted, not confirmed: check subsequent feedback.

## Samsung / 4VRS address boundary

**2449 ends the Samsung factory indoor-unit range; 2450 starts the custom 4VRS extensions.**
This does not mark the end of all Samsung addressing: factory MessageSet 6000/7000
is separate and is not implemented here.

| PDU range | Origin | Implementation |
|---|---|---|
| 50–99 | Samsung IU0 | Assigned: 50–55, 57–59 |
| 100–2449 | Samsung IU1–IU47 | Reserved; this controller serves IU0 only |
| **2450–2474** | **4VRS custom extension begins** | Additional UART catalog |
| 2475–2483 | 4VRS | Diagnostics and command results |
| 2484–2487 | 4VRS | Full swing, presets, full fan including Turbo, Quiet |
| 2488–2499 | 4VRS reserve | Unassigned |
| 2500–2949 | 4VRS | Raw catalog payloads and freshness |

Unassigned addresses are not readable zero-filled registers. Matching Samsung
addresses does not imply complete factory-adapter emulation; see the semantics below.

## Implemented factory positions (IU0)

| PDU | Access | Meaning and values |
|---:|---|---|
| 50 | R | Locally derived communication bits: 0 before feedback, 7 ready, 11 after feedback expires |
| 51 | R | Unit type: FFFF (unknown); raw Wi-Fi model bytes are not a NASA type |
| 52 | R/W | Power: 0 off, 1 on |
| 53 | R/W | Mode: 0 Auto, 1 Cool, 2 Dry, 3 Fan, 4 Heat |
| 54 | R/W | Fan: 0 Auto, 1 Low, 2 Medium, 3 High |
| 55 | R/W | Vertical swing: 0 off, 1 on; preserves horizontal swing |
| 57 | W | Filter reset: 0 no action, 1 submits experimental UART 13/44=00 |
| 58 | R/W | Target ×10; supported UART values 160–300, multiples of 10 |
| 59 | R | Room temperature ×10, signed int16 |

Example: FC06 address 58 value 240 requests 24°C. FC03 address 52 count 4 reads
power/mode/fan/vertical swing. FC04 address 58 count 2 reads both temperatures.
One-based software displays PDU52 as register 53 (often holding reference 40053).
Always distinguish PDU addresses from display notation.

The factory map has no ordinary indoor Turbo fan code: read 54 returns 0B while
Turbo is reported. Use custom 2486 to observe/control it. Out-of-range values in
factory 52–55 are acknowledged and ignored, as documented; they send no UART
command. Fractional or out-of-range targets are rejected (03), not rounded.
Mode changes preserve power. The AC may impose additional mode-specific limits.
Filter reset is implemented from the legacy UART source but has NOT been tested
on this AC; ACK alone cannot prove that the reminder was cleared.

## Reserved manufacturer positions

The product definition uses the actual functions listed here, without placeholder
entities for other Samsung equipment. Unassigned manufacturer addresses stay reserved
for future matching functions. In particular, 69–71 belong to ERV equipment rather
than the room AC Fan mode; 78 is hydro Quiet. Our room AC Quiet uses2487.
The raw error/beep catalog stays available with its original bytes. Use the readable
ranges above: a request crossing an unassigned address fails as a whole (02).

## Custom continuation after the complete factory indoor range

These addresses belong to **our project**, not Samsung. No compatibility aliases for other devices are provided.

| PDU | Access | Meaning |
|---:|---|---|
| 2450–2474 | R / selected W | Raw one-byte UART catalog: address = 2450 + index |
| 2475 | R | Last core status age in seconds; 65535 if never received |
| 2476–2477 | R | Core status frame count, low/high words |
| 2478 | R | Core command result: 0 idle, 1 pending, 2 confirmed, 3 timeout, 4 cancelled |
| 2479 | R | Flags: bit0 core fresh, bit1 RTU configured, bit2 TCP configured, bit3 TX enabled |
| 2480 | R | UART TX enabled; cannot be changed through Modbus |
| 2481 | R | Extended result: same codes, plus 5 acknowledged/unverified action |
| 2482 | R | Last extended catalog index; 255 if none |
| 2483 | R | Catalog size (25) |
| 2484 | R/W | Swing: 0 off, 1 vertical, 2 horizontal, 3 both |
| 2485 | R/W | Preset: 0 none, 1 boost, 2 sleep, 3 quiet, 4 legacy smart, 5 soft cool, 6/7/8 legacy wind |
| 2486 | R/W | Full UART fan: 1 Low, 2 Medium, 3 High, 4 Auto, 5 Turbo |
| 2487 | R/W | Quiet: 0 off, 1 on; turning off preserves other active presets |
| 2488–2499 | — | Reserved by this project |
| 2500–2949 | R | Raw catalog blocks: `2500 + 18*index`; length, 16 packed words, age |

See [UART catalog and write allowlist](FUNCTIONS_RU.md). Both read functions may
read custom fields; write-only actions are not exposed as a claimed persistent state.
Raw catalog bytes retain their literal meaning, including FE/FC/FF responses.

## Migration and product behavior

This release changes the external contract; it is not backward compatible with 0.2.0:
coil0 → holding52; target0 → 58 with ×10; mode1 → 53 with Samsung values;
fan2 → 54 (Turbo uses2486); swing4 →2484; preset5 →2485; quiet coil1 →2487.
Raw holding100+index →2450+index; input4–12 →2475–2483;
raw input200+18*index →2500+18*index. RTU changes from19200 8N1 to9600 8E1.
Update controller configuration before installing the firmware.

Unlike the factory adapter's retained cache, unknown/stale feedback returns0B;
we do not publish a plausible temperature, mode or error code without evidence.
Per-field read expiry is30s; writes require fresh core and affected fields within10s.
Communication word50 is derived from UART feedback, not actual NASA tracking.
Firmware0.4.2 enables UART after every reboot at the owner's request; older versions
started monitor-only. Exceptions:01 unsupported FC,02 address,
03 value/batch,06 busy or TX disabled,0B unknown/stale/unrepresentable state.
Repeated writes are commands, not a way to poll. Keep requests at least10ms apart.

Host tests cover factory conversions, signed scaling, swing-axis preservation,
ignored values, atomic writes, unsupported functions, extension isolation and the
existing UART confirmation/freshness/parser tests. A successful build does not
constitute live testing of the new map, physical RS485 or an external MIM integration.

## Runtime settings in0.4.0

MQTT, RTU and TCP now have independent persistent checkboxes on the portal. RTU and TCP
default off on first0.4.0 startup. Unit/baud are configured in the browser; parity stays Even.
Diagnostic2479 bits1/2 reflect enabled transports. Register addresses remain unchanged.

## Register reference

[Register information sheet in Russian](MODBUS_REGISTERS_RU.md):
addresses, values, write confirmation, raw catalog and polling behavior.

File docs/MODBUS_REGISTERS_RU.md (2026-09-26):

# Samsung-ESP32-MQTT-Modbus — информационный лист регистров

Производитель контроллера: **4vrs**. Прошивка: **0.5.0**. Версия карты: **0.3.0**.

ESP32 переводит Modbus TCP/RTU в D0 UART кондиционера Samsung. Совпадающие основные
функции используют адреса MIM-B19N/B19NT; дополнительные функции контроллера размещены
с адреса 2450. Один контроллер обслуживает один внутренний блок (IU0).
Все адреса ниже десятичные, от нуля. R — чтение, W — запись.

## Граница заводской карты Samsung и расширений 4VRS

**2449 — конец заводского диапазона внутренних блоков MIM-B19N/B19NT.
2450 — начало наших дополнительных регистров 4VRS.**

Это граница диапазона внутренних блоков, а не всей адресации Samsung:
заводские служебные MessageSet 6000/7000 остаются отдельно и здесь не реализованы.

| Адреса PDU | Происхождение / назначение | Что реализовано в Samsung-ESP32 |
|---|---|---|
| 50–99 | Заводская карта Samsung, внутренний блок IU0 | 50–55, 57–59; подробности ниже |
| 100–2449 | Заводской диапазон остальных внутренних блоков IU1–IU47 | Зарезервирован; наш контроллер обслуживает один блок IU0 |
| **2450–2474** | **Начало расширений 4VRS** | Дополнительный каталог UART-параметров |
| 2475–2483 | Расширения 4VRS | Диагностика, свежесть данных, результаты команд |
| 2484–2487 | Расширения 4VRS | Обе оси жалюзи, пресеты, полная скорость с Turbo, Quiet |
| 2488–2499 | Резерв 4VRS | Не назначены |
| 2500–2949 | Расширения 4VRS | Полные raw-ответы каталога, длина и возраст данных |

Совпадение адресов основных функций с Samsung не означает полную эмуляцию
заводского адаптера: особенности данных 50/51 и проверки свежести описаны ниже.
Неназначенные адреса не являются читаемыми регистрами с нулевым значением.

## Подключение и адресация

| Параметр | Значение |
|---|---|
| Modbus TCP | Порт 502, адрес контроллера настраивается пользователем |
| Modbus RTU | 9600 бод по умолчанию, 8 бит, Even, 1 стоп-бит |
| Возможные скорости RTU | 9600, 19200, 38400, 57600, 115200 |
| Slave / unit ID | По умолчанию 1, настройка 1–247; используется и для TCP |
| Чтение | FC03 holding или FC04 input — одинаковая карта чтения |
| Запись | FC06 одного holding-регистра, FC16 нескольких |
| Coils | Нет: FC01/05/15 возвращают exception 01 |
| Настройка транспортов | `http://<IP>/modbus`, независимые checkbox RTU/TCP |

Транспорты по умолчанию выключены, включаются владельцем. С прошивки 0.4.2 UART включён при каждой загрузке; локальный
выключатель UART остаётся. В 0.4.0–0.4.1 требовалось включать UART после перезапуска.
Сохранение MQTT-настроек в 0.4.2 перезагружает плату, что кратковременно прерывает Modbus.

**Все адреса далее — десятичные, zero-based PDU. Ничего не прибавлять.**
Например, адрес 52 передаётся как 52 (0x0034). В интерфейсе с one-based нотацией
он может называться 53 или 40053. Не передавать 40053 в PDU.
IU0 фиксирован и не зависит от unit ID. Формула заводского диапазона:
`50 + 50*IU + offset`, IU=0..47. Его конец — 2449; расширения начинаются с 2450.

## Регистры по заводской карте Samsung — IU0

Один регистр = 16 бит. По сети старший байт идёт первым. Все слова unsigned,
если явно не указан signed int16.

| PDU | Доступ | Тип / масштаб | Назначение |
|---:|---|---|---|
| 50 | R | uint16 enum | Связь: 0 — нет полного свежего состояния; 7 — готов; 11 — есть известные поля, но полный набор не свежий |
| 51 | R | uint16 | Тип блока: 65535 / FFFF, неизвестен; не использовать как модель или идентификатор |
| 52 | R/W | uint16 enum | Питание: 0 выкл., 1 вкл. |
| 53 | R/W | uint16 enum | Режим: 0 auto, 1 cool, 2 dry, 3 fan_only, 4 heat |
| 54 | R/W | uint16 enum | Заводская скорость: 0 auto, 1 low, 2 medium, 3 high; для основной сущности предпочтительнее 2486 |
| 55 | R/W | uint16 bool | Вертикальное качание: 0 выкл., 1 вкл.; запись сохраняет горизонтальное |
| 57 | W | uint16 action | Сброс напоминания фильтра: записать 1; 0 — ничего не делать |
| 58 | R/W | uint16 ×0.1 °C | Заданная температура: 160..300, только кратные 10, то есть 16..30 °C шагом 1 °C |
| 59 | R | int16 ×0.1 °C | Температура помещения, сначала преобразовать two's complement в signed |

При Turbo чтение 54 возвращает **exception 0B**, не 5. Поэтому не включать 54
в обязательный общий блок климатических данных. У 54 и 2486 **разные коды Auto**.
56 не назначен; 57 нельзя читать. Запрос 52..59 целиком не работает.

Режим 53 не меняет питание 52. Одновременное включение и выбор режима выполняется
FC16 по адресу 52 с двумя значениями `[1, mode]`. Для отключения достаточно 52=0.
Quiet 2487 и preset 2485 относятся к одному полю; их нельзя писать одним пакетом.

## Дополнительное управление 4VRS — 2484–2487

Эти адреса разработаны для Samsung-ESP32 и не относятся к заводской карте Samsung.

| PDU | Доступ | Тип / масштаб | Назначение |
|---:|---|---|---|
| 2484 | R/W | uint16 enum | Полное качание: 0 off, 1 vertical, 2 horizontal, 3 both |
| 2485 | R/W | uint16 enum | Preset: 0 none, 1 boost, 2 sleep, 3 quiet, 4 legacy smart, 5 legacy soft cool, 6/7/8 legacy wind 1/2/3 |
| 2486 | R/W | uint16 enum | Полная скорость UART: 1 low, 2 medium, 3 high, 4 auto, 5 turbo |
| 2487 | R/W | uint16 bool | Quiet: 1 включает preset=3; 0 снимает quiet, но сохраняет другой активный preset |

## Подтверждение команд и доступность

Modbus-положительный ответ — команда принята, **не доказательство выполнения**.
Не переключать отображаемое состояние оптимистично. Состояние получается от AC.
Ответ UART на запись тоже не равен фактическому изменению состояния.

- Свежесть чтения отдельного поля — менее 30 секунд.
- Для записи требуется UART включён, отсутствие pending-команды и свежие основные
  поля/затрагиваемые поля менее 10 секунд.
- Основные поля CORE: питание, уставка, режим, скорость. Температура комнаты,
  качание и preset могут отсутствовать отдельно; наличие CORE не гарантирует их.
- Основной UART-опрос идёт примерно каждые 5 секунд. Modbus читает кэш, не запускает
  немедленный UART-опрос каждого запрошенного регистра.
- Pending-команда завершается по обратной связи либо через 10 секунд таймаутом.
- Общий UART ресурс один: команды Modbus, MQTT и веб-пульта могут конфликтовать по busy.

Записи выполняются последовательно. После записи проверять
результат и целевые поля; не считать старое result=2 подтверждением новой команды.
Нет отдельного Modbus transaction ID для UART-команды: при нескольких управляющих
клиентах подтверждение имеет ограничения. Не повторять автоматически кнопки сброса.

| Exception | Значение | Обработка ответа |
|---|---|---|
| 01 | Неподдерживаемая функция | Исправить FC, не повторять бесконечно |
| 02 | Неназначенный адрес / запрещённый доступ | Исправить адрес или разбить диапазон |
| 03 | Недопустимое значение/пакет | Не округлять и не повторять без изменения |
| 06 | Busy, UART выключен или передача сейчас невозможна | Ограниченный отложенный повтор обычной команды; проверить 2480 |
| 0B | Нет свежего/представимого состояния | Поле unknown/unavailable; не подставлять ноль |

Ошибка 0B относится к запрошенным данным, а не ко всем функциям контроллера.
Сохранение последнего значения возможно только с пометкой недостоверности, а не
как актуальное измерение. При отсутствии свежего CORE климат не считать готовым.
При потере TCP/RTU делать недоступным устройство; диагностика 50/2479 позволяет
отличить ответ контроллера от свежей связи с кондиционером.

Особенность совместимости: неверные значения 52–55 подтверждаются и игнорируются
(UART-команда не отправляется). Проверять диапазоны на стороне UI обязательно.
Неверная уставка 58, включая дробный шаг, возвращает 03.

## Диагностические регистры 4VRS — 2475–2483

| PDU | Значение |
|---:|---|
| 2475 | Возраст последнего core status frame в секундах, saturate 65535; 65535 также «никогда» |
| 2476 | Младшее слово счётчика core status frames |
| 2477 | Старшее слово счётчика; total = reg2476 + (reg2477 << 16) |
| 2478 | Последний результат основной команды: 0 idle, 1 pending, 2 confirmed, 3 timeout/unconfirmed, 4 cancelled |
| 2479 | Биты: 0 CORE fresh, 1 RTU enabled, 2 TCP enabled, 3 UART TX enabled |
| 2480 | UART TX enabled 0/1, только чтение |
| 2481 | Результат extended: 0..4 как выше, 5 acknowledged/unverified action |
| 2482 | Последний extended index 0..24; 255 если не было |
| 2483 | Размер каталога: 25 |

2475 — возраст кадра, не гарантия свежести всех его полей. Счётчик 32-битный,
порядок слов **low, high**, не обычный high, low. В пределах слова порядок байт
стандартный Modbus. 2480 нельзя использовать как Modbus-switch с записью.
Включение extended polling тоже не имеет Modbus-регистра.

## Каталог расширений 4VRS — 2450–2474

Однобайтовый регистр `2450 + index` читается только при свежем значении длиной
ровно один байт. Иначе 0B. Для многобайтовых ответов использовать raw-блок ниже.
У всех строк есть raw-обратная связь, но это не обещание, что конкретная модель
вернёт значение. Названия legacy взяты из разобранного UART-протокола.

| Index | PDU | UART group/id hex | Назначение | Разрешённая запись (десятичные коды) |
|---:|---:|---|---|---|
| 0 | 2450 | 12/73 | Sleep flag legacy | 0 enabled, 255 disabled |
| 1 | 2451 | 13/32 | Auto clean | 34 enabled, 35 disabled |
| 2 | 2452 | 13/75 | Ionizer SPI legacy | 15 enabled, 240 disabled |
| 3 | 2453 | 13/40 | Energy setting raw | 0..255, шаг 1; единицы не установлены |
| 4 | 2454 | 13/44 | Reset filter reminder | Только 0; action |
| 5 | 2455 | 14/E9 | Filter interval legacy | 0..4; UI-метки 0/180/300/500/700, единицы не подтверждены |
| 6 | 2456 | 14/E8 | Reset usage counters | Только 1; action |
| 7 | 2457 | 12/74 | Beep raw | Нет |
| 8 | 2458 | 12/F7 | Error bytes | Нет |
| 9 | 2459 | 13/76 | Outdoor temperature raw | Нет |
| 10 | 2460 | 13/77 | Cooling capability raw | Нет |
| 11 | 2461 | 13/78 | Heating capability raw | Нет |
| 12 | 2462 | 14/32 | Power raw | Нет |
| 13 | 2463 | 14/E0 | Energy raw | Нет |
| 14 | 2464 | 14/E4 | Runtime raw | Нет |
| 15 | 2465 | 14/E6 | Filter usage raw | Нет |
| 16 | 2466 | 14/F6 | Main version | Нет |
| 17 | 2467 | 14/F4 | Panel version | Нет |
| 18 | 2468 | 14/F3 | Outdoor version | Нет |
| 19 | 2469 | 14/F5 | Model code | Нет |
| 20 | 2470 | 14/39 | Option code | Нет |
| 21 | 2471 | 12/01 | Control enable raw | Нет |
| 22 | 2472 | 14/37 | WiFi status raw | Нет |
| 23 | 2473 | 14/38 | Internet status raw | Нет |
| 24 | 2474 | 12/63 | Airflow direction legacy | 18,33,49,65,81,97,113,129,130,146,162,178,194 |

Для 2474 метки текущего веб-пульта по порядку: Off, Indirect, Direct, Center,
Wide, Left, Right, Long, Legacy vertical 82, Vertical, Horizontal, Both, Fixed.
Это экспериментальный raw select. Для обычного swing использовать **2484**:
на испытательном блоке остановка качания проверена через raw C2=194;
legacy Off=18 не заменяет проверенное выключение через нормализованный регистр.

Кнопка фильтра: либо заводской action **57=1**, либо raw action **2454=0**,
не обе команды. 57 не имеет читаемого состояния. Чтение raw 2454 при наличии
байта не означает, что сброс выполнен. Результат 2481=5 означает только ACK
действия без доказанного сброса счётчика/напоминания.

Физические единицы raw-параметров не подтверждены: значения Power, Energy, Runtime,
Outdoor temperature не являются готовыми измерениями W, kWh, часов или °C.
FE/FC/FF — реальные байты ответа; не трактовать автоматически как «нет ошибки»,
отрицательную температуру или unsupported.

## Raw-блоки 4VRS — 2500–2949

Для каждого index 0..24 начало `B = 2500 + 18*index`:

| Offset | Содержимое |
|---:|---|
| 0 | Длина полезных данных, до 32 байт |
| 1..16 | По два исходных байта в слове, первый байт в старших 8 битах |
| 17 | Возраст в секундах, saturate 65535; неизвестное значение тоже 65535 |

Например, index 8 (ошибки): B=2644, данные 2645..2660, возраст 2661.
Index 24: B=2932, данные 2933..2948, возраст 2949.
Декодирование: для каждого слова `[word >> 8, word & 255]`, обрезать массив по длине.
Не менять порядок слов, не декодировать версии/модель как число или ASCII без проверки.

Возраст читается даже при устаревших/неизвестных данных. Остальные слова такого
блока возвращают 0B при устаревании; весь групповой запрос тогда тоже завершается
ошибкой. Для надёжной диагностики читать возраст отдельно от payload. Не опрашивать
все 450 слов одним диапазоном и не объединять разные raw-блоки в обязательный запрос.

**Extended status polling по умолчанию выключен даже в 0.4.2.** В веб-пульте
его можно включить локально; есть кнопка разового чтения extended. Modbus не включает
опрос автоматически. При включении каталог обходится по одному элементу с интервалом
не менее 800 мс, с приоритетом core/служебных обменов, поэтому отдельные значения
могут устаревать. Это ожидаемая причина 0B, а не повод скрывать весь Device.

## Ограничения пакетных запросов

FC16 максимум 8 слов. Вся последовательность сначала валидируется, затем
отправляется одна UART-команда. Нельзя смешивать core и extended, несколько extended,
или разные адреса одного и того же нормализованного поля. FC16 — только непрерывные
адреса: нельзя передать «разреженную» карту. Для расширений предпочтителен FC06.
Пакет 2484..2487 неверен, поскольку preset 2485 и quiet 2487 оба меняют PRESET.
Между запросами выдерживается не менее 10 мс.

Неназначенные 56, 60.., 2488..2499 и прочие пробелы не заполнять нулями.
Регистр 69..71 заводского адаптера относится к ERV, не нашему fan_only;
78 — quiet гидромодуля, для нашего quiet использовать 2487.
Не использовать заводские MessageSet 6000/7000: наш контракт их не реализует.

## Источники

- [Карта Modbus (English)](MODBUS.md)
- [Адреса и преобразования в прошивке](../components/samsung_uart/bridge.h)
- [Расширенный каталог и допустимые значения](../components/samsung_uart/extended.h)
- [UART-функции и статус аппаратных проверок](FUNCTIONS_RU.md)

Наличие регистра в прошивке не гарантирует поддержку функции каждой моделью Samsung.
Основные функции вентиляции проверены на AR24BSFCMWKNER; расширенные legacy-функции
требуют проверки на конкретном кондиционере. Неизвестные данные сохраняют raw-формат.

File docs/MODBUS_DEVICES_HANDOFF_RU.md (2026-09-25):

# Задание для Modbus Devices: 4vrs → Samsung-ESP32-MQTT-Modbus

## Цель и границы

Добавить новое устройство производителя **4vrs**, модель **Samsung-ESP32-MQTT-Modbus**,
в существующий проект Modbus Devices для Home Assistant. Использовать архитектуру,
схему описаний, локализацию и соглашения самого Modbus Devices; данный документ
задаёт протокольный контракт, а не выдуманный формат его конфигурационных файлов.

Репозиторий устройства: https://github.com/dk-1983/Samsung-ESP32-MQTT-Modbus

Базовая прошивка: **0.4.2**, карта регистров: **0.3.0** (адреса не изменились в 0.4.x).
Контракт сверен с исходниками коммита **1bdbae7**, включая `bridge.h`, `extended.h`,
`protocol.h`, `samsung_uart.cpp` и `samsung-s3.yaml`.

Это собственный UART–Modbus/MQTT контроллер 4vrs на ESP32-S3 N16R8. Кондиционер
Samsung подключён через UART штатного Wi-Fi-модуля, D0-профиль; сам кондиционер
не является Modbus slave. Испытательный внутренний блок — **AR24BSFCMWKNER**.
Облако Samsung не требуется. MQTT и Modbus независимы; для этого Device MQTT не нужен.

Не создавать устройство под именем заводского MIM-B19N: у нас своя полная карта.
Совпадающие функции размещены по карте Samsung MIM-B19N/B19NT, дополнительные —
после всего диапазона 48 внутренних блоков. Не переносить адреса Haier YCJ-A002.
Не создавать заглушки сущностей для функций других Samsung-систем. Все функции
нашего контроллера включить в описание; экспериментальные обозначить честно,
сохранить доступ к ним и к исходным данным, не выдавая их за проверенные измерения.

## Подключение и адресация

| Параметр | Значение |
|---|---|
| Modbus TCP | Порт 502, адрес контроллера настраивается пользователем |
| Адрес текущего стенда | 10.0.0.15; не зашивать его в шаблон устройства |
| Modbus RTU | 9600 бод по умолчанию, 8 бит, Even, 1 стоп-бит |
| Возможные скорости RTU | 9600, 19200, 38400, 57600, 115200 |
| Slave / unit ID | По умолчанию 1, настройка 1–247; используется и для TCP |
| Чтение | FC03 holding или FC04 input — одинаковая карта чтения |
| Запись | FC06 одного holding-регистра, FC16 нескольких |
| Coils | Нет: FC01/05/15 возвращают exception 01 |
| Настройка транспортов | `http://<IP>/modbus`, независимые checkbox RTU/TCP |

Транспорты по умолчанию выключены, включаются владельцем. Текущий выбор на стенде
не считать константой. С прошивки 0.4.2 UART включён при каждой загрузке; локальный
выключатель UART остаётся. В 0.4.0–0.4.1 требовалось включать UART после перезапуска.
Сохранение MQTT-настроек в 0.4.2 перезагружает плату, что кратковременно прерывает Modbus.

**Все адреса далее — десятичные, zero-based PDU. Ничего не прибавлять.**
Например, адрес 52 передаётся как 52 (0x0034). В интерфейсе с one-based нотацией
он может называться 53 или 40053. Не передавать 40053 в PDU.
IU0 фиксирован и не зависит от unit ID. Формула заводского диапазона:
`50 + 50*IU + offset`, IU=0..47. Его конец — 2449; расширения начинаются с 2450.

## Основные регистры и сущности

Один регистр = 16 бит. По сети старший байт идёт первым. Все слова unsigned,
если явно не указан signed int16.

| PDU | Доступ | Тип / масштаб | Назначение |
|---:|---|---|---|
| 50 | R | uint16 enum | Связь: 0 — нет полного свежего состояния; 7 — готов; 11 — есть известные поля, но полный набор не свежий |
| 51 | R | uint16 | Тип блока: 65535 / FFFF, неизвестен; не использовать как модель или идентификатор |
| 52 | R/W | uint16 enum | Питание: 0 выкл., 1 вкл. |
| 53 | R/W | uint16 enum | Режим: 0 auto, 1 cool, 2 dry, 3 fan_only, 4 heat |
| 54 | R/W | uint16 enum | Заводская скорость: 0 auto, 1 low, 2 medium, 3 high; для основной сущности предпочтительнее 2486 |
| 55 | R/W | uint16 bool | Вертикальное качание: 0 выкл., 1 вкл.; запись сохраняет горизонтальное |
| 57 | W | uint16 action | Сброс напоминания фильтра: записать 1; 0 — ничего не делать |
| 58 | R/W | uint16 ×0.1 °C | Заданная температура: 160..300, только кратные 10, то есть 16..30 °C шагом 1 °C |
| 59 | R | int16 ×0.1 °C | Температура помещения, сначала преобразовать two's complement в signed |
| 2484 | R/W | uint16 enum | Полное качание: 0 off, 1 vertical, 2 horizontal, 3 both |
| 2485 | R/W | uint16 enum | Preset: 0 none, 1 boost, 2 sleep, 3 quiet, 4 legacy smart, 5 legacy soft cool, 6/7/8 legacy wind 1/2/3 |
| 2486 | R/W | uint16 enum | Полная скорость UART: 1 low, 2 medium, 3 high, 4 auto, 5 turbo |
| 2487 | R/W | uint16 bool | Quiet: 1 включает preset=3; 0 снимает quiet, но сохраняет другой активный preset |

При Turbo чтение 54 возвращает **exception 0B**, не 5. Поэтому не включать 54
в обязательный общий блок климатических данных. У 54 и 2486 **разные коды Auto**.
56 не назначен; 57 нельзя читать. Запрос 52..59 целиком не работает.

Рекомендуемая основная сущность `climate`:

- power 52 + mode 53 формируют hvac_mode; если power=0, отображать off независимо от 53;
- target_temperature = 58 / 10; current_temperature = signed(59) / 10;
- fan_mode читать и писать через 2486, включая turbo;
- swing_mode через 2484; preset_mode через 2485;
- quiet при необходимости отдельным switch 2487, он связан с preset, а не независим от него.

Для `turn_off` записать 52=0. Для `turn_on` записать 52=1, сохраняя текущий режим.
При выборе рабочего HVAC-режима из off следует включить питание и выбрать режим:
**FC16, старт 52, два значения [1, mode]**. Так это одна UART-команда. Одна запись
53 меняет режим, но **не включает питание**. Если проект умеет только FC06, две
команды отправлять последовательно, дождавшись окончания первой.

Дополнительный switch вертикального качания использует 55. Для отдельного
горизонтального switch отдельного адреса нет: свежий 2484, затем read-modify-write
`(old & 1) | (on ? 2 : 0)`. Не терять другую ось; предпочтительнее единый swing select.
Если основной climate не поддерживает пользовательские presets, добавить select,
а не терять режимы 4..8. Не записывать 2485 и 2487 одним запросом — это одно поле.
Не дублировать основные органы управления множеством включённых по умолчанию сущностей.

## Подтверждение команд и доступность

Modbus-положительный ответ — команда принята, **не доказательство выполнения**.
Не переключать отображаемое состояние оптимистично. Состояние получается от AC.
Ответ UART на запись тоже не равен фактическому изменению состояния.

- Свежесть чтения отдельного поля — менее 30 секунд.
- Для записи требуется UART включён, отсутствие pending-команды и свежие основные
  поля/затрагиваемые поля менее 10 секунд.
- Основные поля CORE: питание, уставка, режим, скорость. Температура комнаты,
  качание и preset могут отсутствовать отдельно; наличие CORE не гарантирует их.
- Основной UART-опрос идёт примерно каждые 5 секунд. Modbus читает кэш, не запускает
  немедленный UART-опрос каждого запрошенного регистра.
- Pending-команда завершается по обратной связи либо через 10 секунд таймаутом.
- Общий UART ресурс один: команды Modbus, MQTT и веб-пульта могут конфликтовать по busy.

В интеграции сделать последовательную очередь записей. После записи проверять
результат и целевые поля; не считать старое result=2 подтверждением новой команды.
Нет отдельного Modbus transaction ID для UART-команды: при нескольких управляющих
клиентах подтверждение имеет ограничения. Не повторять автоматически кнопки сброса.

| Exception | Значение | Поведение интеграции |
|---|---|---|
| 01 | Неподдерживаемая функция | Исправить FC, не повторять бесконечно |
| 02 | Неназначенный адрес / запрещённый доступ | Исправить адрес или разбить диапазон |
| 03 | Недопустимое значение/пакет | Не округлять и не повторять без изменения |
| 06 | Busy, UART выключен или передача сейчас невозможна | Ограниченный отложенный повтор обычной команды; проверить 2480 |
| 0B | Нет свежего/представимого состояния | Поле unknown/unavailable; не подставлять ноль |

0B у одной экспериментальной сущности не должно делать весь Device недоступным.
Сохранение последнего значения возможно только с пометкой недостоверности, а не
как актуальное измерение. При отсутствии свежего CORE климат не считать готовым.
При потере TCP/RTU делать недоступным устройство; диагностика 50/2479 позволяет
отличить ответ контроллера от свежей связи с кондиционером.

Особенность совместимости: неверные значения 52–55 подтверждаются и игнорируются
(UART-команда не отправляется). Проверять диапазоны на стороне UI обязательно.
Неверная уставка 58, включая дробный шаг, возвращает 03.

## Диагностические регистры

| PDU | Значение |
|---:|---|
| 2475 | Возраст последнего core status frame в секундах, saturate 65535; 65535 также «никогда» |
| 2476 | Младшее слово счётчика core status frames |
| 2477 | Старшее слово счётчика; total = reg2476 + (reg2477 << 16) |
| 2478 | Последний результат основной команды: 0 idle, 1 pending, 2 confirmed, 3 timeout/unconfirmed, 4 cancelled |
| 2479 | Биты: 0 CORE fresh, 1 RTU enabled, 2 TCP enabled, 3 UART TX enabled |
| 2480 | UART TX enabled 0/1, только чтение |
| 2481 | Результат extended: 0..4 как выше, 5 acknowledged/unverified action |
| 2482 | Последний extended index 0..24; 255 если не было |
| 2483 | Размер каталога: 25 |

2475 — возраст кадра, не гарантия свежести всех его полей. Счётчик 32-битный,
порядок слов **low, high**, не обычный high, low. В пределах слова порядок байт
стандартный Modbus. 2480 нельзя использовать как Modbus-switch с записью.
Включение extended polling тоже не имеет Modbus-регистра.

## Полный расширенный каталог

Однобайтовый регистр `2450 + index` читается только при свежем значении длиной
ровно один байт. Иначе 0B. Для многобайтовых ответов использовать raw-блок ниже.
У всех строк есть raw-обратная связь, но это не обещание, что конкретная модель
вернёт значение. Названия legacy взяты из разобранного UART-протокола.

| Index | PDU | UART group/id hex | Назначение | Разрешённая запись (десятичные коды) |
|---:|---:|---|---|---|
| 0 | 2450 | 12/73 | Sleep flag legacy | 0 enabled, 255 disabled |
| 1 | 2451 | 13/32 | Auto clean | 34 enabled, 35 disabled |
| 2 | 2452 | 13/75 | Ionizer SPI legacy | 15 enabled, 240 disabled |
| 3 | 2453 | 13/40 | Energy setting raw | 0..255, шаг 1; единицы не установлены |
| 4 | 2454 | 13/44 | Reset filter reminder | Только 0; action |
| 5 | 2455 | 14/E9 | Filter interval legacy | 0..4; UI-метки 0/180/300/500/700, единицы не подтверждены |
| 6 | 2456 | 14/E8 | Reset usage counters | Только 1; action |
| 7 | 2457 | 12/74 | Beep raw | Нет |
| 8 | 2458 | 12/F7 | Error bytes | Нет |
| 9 | 2459 | 13/76 | Outdoor temperature raw | Нет |
| 10 | 2460 | 13/77 | Cooling capability raw | Нет |
| 11 | 2461 | 13/78 | Heating capability raw | Нет |
| 12 | 2462 | 14/32 | Power raw | Нет |
| 13 | 2463 | 14/E0 | Energy raw | Нет |
| 14 | 2464 | 14/E4 | Runtime raw | Нет |
| 15 | 2465 | 14/E6 | Filter usage raw | Нет |
| 16 | 2466 | 14/F6 | Main version | Нет |
| 17 | 2467 | 14/F4 | Panel version | Нет |
| 18 | 2468 | 14/F3 | Outdoor version | Нет |
| 19 | 2469 | 14/F5 | Model code | Нет |
| 20 | 2470 | 14/39 | Option code | Нет |
| 21 | 2471 | 12/01 | Control enable raw | Нет |
| 22 | 2472 | 14/37 | WiFi status raw | Нет |
| 23 | 2473 | 14/38 | Internet status raw | Нет |
| 24 | 2474 | 12/63 | Airflow direction legacy | 18,33,49,65,81,97,113,129,130,146,162,178,194 |

Для 2474 метки текущего веб-пульта по порядку: Off, Indirect, Direct, Center,
Wide, Left, Right, Long, Legacy vertical 82, Vertical, Horizontal, Both, Fixed.
Это экспериментальный raw select. Для обычного swing использовать **2484**:
на испытательном блоке остановка качания проверена через raw C2=194;
legacy Off=18 не заменяет проверенное выключение через нормализованный регистр.

Кнопка фильтра: либо заводской action **57=1**, либо raw action **2454=0**,
не обе команды. 57 не имеет читаемого состояния. Чтение raw 2454 при наличии
байта не означает, что сброс выполнен. Результат 2481=5 означает только ACK
действия без доказанного сброса счётчика/напоминания.

Рекомендуемые сущности расширения: selects/switches для 2450/2451/2452,
number raw 2453, select 2455, buttons сброса фильтра и usage, select 2474,
диагностические raw-сенсоры всех 25 элементов. Не присваивать неподтверждённые
единицы W, kWh, °C, часы и HA device_class/state_class исходным байтам.
FE/FC/FF — реальные байты ответа; не трактовать автоматически как «нет ошибки»,
отрицательную температуру или unsupported.

## Raw-блоки 2500–2949

Для каждого index 0..24 начало `B = 2500 + 18*index`:

| Offset | Содержимое |
|---:|---|
| 0 | Длина полезных данных, до 32 байт |
| 1..16 | По два исходных байта в слове, первый байт в старших 8 битах |
| 17 | Возраст в секундах, saturate 65535; неизвестное значение тоже 65535 |

Например, index 8 (ошибки): B=2644, данные 2645..2660, возраст 2661.
Index 24: B=2932, данные 2933..2948, возраст 2949.
Декодирование: для каждого слова `[word >> 8, word & 255]`, обрезать массив по длине.
Не менять порядок слов, не декодировать версии/модель как число или ASCII без проверки.

Возраст читается даже при устаревших/неизвестных данных. Остальные слова такого
блока возвращают 0B при устаревании; весь групповой запрос тогда тоже завершается
ошибкой. Для надёжной диагностики читать возраст отдельно от payload. Не опрашивать
все 450 слов одним диапазоном и не объединять разные raw-блоки в обязательный запрос.

**Extended status polling по умолчанию выключен даже в 0.4.2.** В веб-пульте
его можно включить локально; есть кнопка разового чтения extended. Modbus не включает
опрос автоматически. При включении каталог обходится по одному элементу с интервалом
не менее 800 мс, с приоритетом core/служебных обменов, поэтому отдельные значения
могут устаревать. Это ожидаемая причина 0B, а не повод скрывать весь Device.

## Опрос и запись: рекомендуемая организация

Интервалы ниже — рекомендации для интеграции, не новые требования прошивки:

- Основные независимые чтения раз в 5 секунд: 50..53, 58..59, 2486.
- 2484, 2485, 2487 читать отдельно, чтобы отсутствие одного поля не срывало остальные.
- Диагностика 2475..2483 — безопасный сплошной диапазон из 9 слов, раз в 5–10 секунд.
- 54/55 — опциональные совместимые сущности; не ставить 54 в обязательный polling.
- Extended — отдельные запросы, обычно 15–30 секунд; raw payload лучше по требованию.
- Между запросами не менее 10 мс; последовательная очередь удобнее параллельной.
- После записи можно временно опрашивать её результат раз в секунду в течение 10–12 с.

FC16 максимум 8 слов. Вся последовательность сначала валидируется, затем
отправляется одна UART-команда. Нельзя смешивать core и extended, несколько extended,
или разные адреса одного и того же нормализованного поля. FC16 — только непрерывные
адреса: нельзя передать «разреженную» карту. Для расширений предпочтителен FC06.
Пакет 2484..2487 неверен, поскольку preset 2485 и quiet 2487 оба меняют PRESET.

Неназначенные 56, 60.., 2488..2499 и прочие пробелы не заполнять нулями.
Регистр 69..71 заводского адаптера относится к ERV, не нашему fan_only;
78 — quiet гидромодуля, для нашего quiet использовать 2487.
Не использовать заводские MessageSet 6000/7000: наш контракт их не реализует.

## Проверки реализации в Modbus Devices

1. Правильная регистрация производителя/модели и выбор TCP либо RTU средствами проекта.
2. Адреса без off-by-one; unit ID независим от IU0; FC03/04/06/16, никаких coils.
3. 58=240 отображается как 24 °C; установка 24 °C пишет 240; шаг 1 °C.
4. Signed room: слово 0xFFCE превращается в -5.0 °C, не 6548.6 °C.
5. HVAC off зависит от power; выход из off выбирает power+mode, а не только mode.
6. Turbo через 2486=5; ошибка 54 не отключает остальные сущности.
7. Качание обеих осей и quiet сохраняют незатрагиваемое состояние.
8. 0B не превращается в 0; 06 обрабатывается без бесконечного потока команд.
9. Нет оптимистичного подтверждения на Modbus ACK; pending/timeout видны корректно.
10. Counter low=0x5678, high=0x1234 → 0x12345678; raw 0x1234 → байты 12 34.
11. Кнопки действий не повторяются автоматически и не изображаются как постоянный switch.
12. При выключенном extended polling основные функции доступны, raw-сущности могут быть unknown.
13. При перезапуске ESP32 интеграция восстанавливается без ручного переустройства.

Сначала использовать имеющиеся в Modbus Devices тесты/фикстуры с имитацией регистров.
Не менять прошивку Samsung и карту ради удобства шаблона. Если формат интеграции не
умеет объединённую запись power+mode или частичную доступность, явно описать ограничение
и реализовать безопасную последовательность средствами проекта.

## Что уже проверено, а что предстоит

На реальном кондиционере подтверждены включение/выключение, скорости Low/Medium/High/Turbo,
качание обеих осей. В 0.4.x проверены web-настройки, ответы Modbus TCP, GitHub OTA
0.4.0→0.4.1. В 0.4.2 проверены автоматическая перезагрузка после сохранения MQTT,
сохранение настроек, восстановление MQTT, автоматический UART и свежая обратная связь.
Хост-тесты покрывают карту, преобразования, очередь/подтверждение, свежесть и парсер.

Полный сценарий будущего Device Modbus Devices, физический RTU и все экспериментальные
extended-функции ещё требуют проверки. Для стендовых управляющих тестов владелец ранее
разрешил вентиляцию; не переключать автономно на охлаждение или обогрев.

## Источники истины для разработчика

- [bridge.h — адреса, преобразования, ошибки, запись](../components/samsung_uart/bridge.h)
- [extended.h — каталог и allowlist](../components/samsung_uart/extended.h)
- [protocol.h — состояние и подтверждение](../components/samsung_uart/protocol.h)
- [samsung_uart.cpp — опрос и UART](../components/samsung_uart/samsung_uart.cpp)
- [samsung-s3.yaml — названия и значения UI](../samsung-s3.yaml)
- [Карта Modbus](MODBUS.md), [каталог функций](FUNCTIONS_RU.md)

При расхождении старых документов и текущего кода ориентироваться на указанную
версию исходников. Упоминания monitor-only на старте относятся к старым версиям:
для 0.4.2 владелец явно выбрал включение UART всегда. Прошивка 0.4.2 установлена
локально на стенд; наличие исходников в main не означает наличие публичного OTA-релиза
с тем же номером. Опубликованный на момент передачи предрелиз — v0.4.1.

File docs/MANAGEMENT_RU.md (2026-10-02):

# Настройки и GitHub OTA — Samsung-ESP32 1.0.2

[English](MANAGEMENT.md)

## Язык портала (1.0.1)

Портал на порту 80 по умолчанию использует English. В навигации можно выбрать
English / Русский; выбор хранится в cookie `samsung_ui_lang` браузера на год
(`Path=/`, `SameSite=Lax`). Отсутствующее или неподдерживаемое значение означает
English. Выбор применяется ко всем страницам портала, включая сброс Wi-Fi.
Страница перезагружается, несохранённые изменения формы теряются. Настройки
контроллера и NVS не меняются, перезагрузка устройства не требуется. После удаления
cookie, смены браузера или адреса снова используется English. Язык расширенного
пульта ESPHome на порту 8080 этим переключателем не управляется.

### Проверки локализации

Источником остаются русские шаблоны страниц. Файл
`components/samsung_portal/i18n/en.tsv` содержит переводы UI на English.
После изменения шаблона или перевода выполните `python tools/build_ui_translations.py`
и включите сгенерированный `UiEnglish.h` в изменения. `./Build.ps1 -TestOnly`
проверяет полноту переводов, контракты форм, все девять языковых маршрутов и
реальный C++-рендерер страниц, а также тесты протокола и моста.

Браузерные проверки используют закреплённый Playwright из `tests/ui/package.json`
и имитацию API, без обращения к контроллеру. После host-тестов выполните:

```text
npm install --prefix tests/ui --ignore-scripts --no-package-lock
node tests/ui/node_modules/playwright/cli.js install chromium
node tests/ui/browser.cjs
```

Workflow публичной сборки выполняет эти проверки до компиляции OTA-образа.
Проверяются English/Русский, настольная/мобильная вёрстка, сохранение языка,
формы, устаревшие/недоступные данные и диалоги подтверждения. Эти проверки не
подтверждают загрузку прошивки или работу устройства. Сначала опубликуйте и
проверьте OTA-файл, затем обновите подписанный стабильный канал; его подписанный
payload нельзя редактировать вручную.

## Локальное управление

### Wi-Fi (0.4.5)

`/wifi` показывает SSID, IP, MAC станции, сигнал в dBm, канал и состояние
точки настройки. `/wifi/reset` — отдельная страница удаления только сохранённой
сети. Перед сбросом нужно знать текущий пароль Samsung-Setup. После подтверждения
контроллер удаляет запись сети и перезагружается через 2 секунды; MQTT, Modbus,
web/OTA/AP-пароли и настройки обновлений сохраняются.

Подключитесь к Samsung-Setup и откройте `http://192.168.4.1:8080/` для ввода
новой сети 2,4 ГГц. После явного сброса старая сеть не восстанавливается автоматически.
При обычной потере связи точка настройки запускается примерно через 10 секунд;
это не удаляет сохранённую сеть.

Авторизованный GET `/wifi/status` возвращает только информацию о соединении,
без паролей. GET `/wifi/reset` ничего не удаляет. POST требует авторизацию,
CSRF `token` и `confirm=RESET_WIFI`; блокируется во время OTA, перезапуска
или pending-команды AC. Запись удаляется адресно из NVS, общий сброс не вызывается.
Сборка требует provisioning через captive portal без вшитых station networks;
это проверяется валидатором конфигурации. Формат ключа соответствует закреплённой
версии ESPHome и должен перепроверяться при её обновлении.

На рабочем стенде проверяются чтение и защита запросов. Реальное удаление сети
и повторное подключение требуют отдельной проверки с доступом к Samsung-Setup.

### Пароли (0.4.4)

Страница `/settings` позволяет независимо изменить пароль веб-интерфейса
(пользователь `admin`, порты 80 и 8080), локального OTA и точки Samsung-Setup.
Для каждого нового пароля требуется повторный ввод. Пустые поля сохраняют
текущее значение. Новые web/OTA-пароли: 16–64 печатных ASCII-символа без пробелов;
точка настройки: 8–63. Существующие web-пароли от 8 символов продолжают работать.

Все поля проверяются перед записью; при ошибке ни один пароль не меняется.
После успешного изменения плата перезагружается через 2 секунды. Если фактически
ничего не изменилось, запись и перезагрузка не выполняются. Пароли сохраняются
одним блоком NVS и переживают OTA. Текущие значения не выдаются через API и не
подставляются в форму. После изменения веб-пароля повторный вход — с новым паролем.
После смены OTA-пароля для следующих локальных загрузок нужен новый пароль;
локальный `secrets.yaml` на компьютере автоматически не изменяется.

Домашний Wi-Fi, MQTT и проверка подписи GitHub-обновлений не затрагиваются.
Во время OTA, запланированного перезапуска или ожидающей команды AC смена
паролей блокируется. Это смена паролей при наличии доступа, а не восстановление
забытого пароля; механизма восстановления пока нет.

API: `GET /settings/config` возвращает только `credentials_ready`.
`POST /settings/config` требует авторизацию, CSRF `token`, пары
`web_password`/`web_confirm`, `ota_password`/`ota_confirm`,
`setup_password`/`setup_confirm`. Пустая или отсутствующая пара сохраняет пароль.
Лишние и повторяющиеся поля отклоняются. Ответ содержит только `changed` и `restarting`.

### О системе и перезагрузка (0.4.3)

Страница `/about` показывает версию, имя, IP, MAC Wi-Fi, время работы,
внутреннюю RAM, PSRAM и Flash. Wi-Fi, MQTT, UART, свежесть данных кондиционера
и выбранные транспорты Modbus отображаются отдельно. MAC — адрес станции Wi-Fi,
подходящий для закрепления IP в DHCP. Технические данные доступны в раскрываемом блоке.

Кнопка «Перезагрузить» требует подтверждения. Настройки сохраняются;
страница ожидает новый запуск и обновляется после восстановления связи.
Во время OTA или ожидающей подтверждения команды AC перезапуск отклоняется.
После загрузки UART включается автоматически. При смене IP страницу нужно
открыть по новому адресу.

API: `GET /system/status`, `POST /system/restart`. Оба требуют авторизации;
POST дополнительно требует текущий CSRF `token` и `confirm=RESTART`. GET не
выполняет перезагрузку. Диагностика не содержит паролей; `boot_id` меняется
при запуске, `uptime_s` показывает длительность работы. `storage_ok` отражает
результат инициализации хранилища, а не непрерывный тест памяти.

Порт80 — страницы `/mqtt`, `/modbus`, `/updates`; веб-пульт и его REST API теперь
на8080. Локальное ESPHome OTA остаётся на3232. После загрузки0.4.0 старые скрипты
HTTP должны обращаться к8080; адреса Modbus соответствуют карте0.3.0.
Пароли страниц одинаковые. При первой локальной загрузке0.4.0 сохраняются web/OTA/AP
пароли из secrets.yaml; далее используются сохранённые значения, включая после GitHub OTA.

На `/mqtt` checkbox разрешает соединение с брокером. Пустое поле нового пароля
сохраняет прежний; отдельный checkbox удаляет пароль. MQTT и HA discovery выключаются
независимо. Начиная с 0.4.2 каждое сохранение MQTT-настроек вызывает
перезапуск через 2 секунды: это пересоздаёт клиент с новым брокером и паролем. После перезапуска UART включён.
Топики и discovery формируются ESPHome.
Уже сохранённые брокером discovery-сообщения не удаляются при снятии checkbox.

На `/modbus` checkbox RTU и TCP независимы. Изменения действуют сразу; существующие
TCP-соединения закрываются. Скорости:9600/19200/38400/57600/115200, формат8E1.
Unit1–247. Выключенный RTU не отвечает, выключенный TCP не слушает502.
Диагностические флаги2479 отражают выбранные состояния транспортов.
Ни один из checkbox не разрешает UART автоматически.

Для первоначального Wi-Fi остаётся ESPHome captive portal на8080. Подключившись
к Samsung-Setup, открыть `http://192.168.4.1:8080/`; ссылка «Настройка Wi-Fi (AP)»
также ведёт туда. Основной портал настроек на80 доступен и при активной AP.

## Обновление

Источник: `https://raw.githubusercontent.com/dk-1983/Samsung-ESP32-MQTT-Modbus/main/releases/stable.json`.
Профиль: `samsung-s3-n16r8-v1`. Образ загружается из Releases этого же репозитория.
Автоматическая установка по умолчанию разрешена; checkbox запрещает
установку, но оставляет проверку. Проверка после старта примерно через минуту,
далее раз в6часов с небольшим случайным сдвигом. Нужны сеть и синхронизированное время.

Перенесены ECDSA P-256 подпись манифеста, HTTPS с проверкой сертификата, проверка
профиля/размера/SHA256/ESP32-S3, отдельный OTA-раздел, подтверждение загрузки и откат.
Новая загрузка считается здоровой после45с работы локальных служб и сети;
сохранённый trial позволяет вернуться к предыдущему слоту при следующем неудачном
запуске или по таймауту. Это пока перенесённый код, а не выполненный тест отката Samsung.
Ключ доверия — открытый ключ издателя 4vrs; закрытый ключ не публикуется.
Профиль и URL Samsung проверяются: манифест другого устройства не принимается.

Локальный OTA и GitHub worker согласованы: worker ждёт разрешения основного цикла;
на время записи GitHub локальный OTA приостановлен. Настройки транспортов во время
GitHub операции не изменяются; запрет обновления можно применить и во время загрузки.

## Релиз
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

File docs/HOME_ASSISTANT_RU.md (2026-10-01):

# Home Assistant через MQTT Discovery

[English](HOME_ASSISTANT.md)

Samsung-ESP32 публикует MQTT Discovery через ESPHome. Отдельная интеграция Samsung,
Hub, HACS или ручное описание сущностей в YAML не нужны.

## Подключение

1. В Home Assistant добавьте штатную интеграцию MQTT: Настройки → Устройства
   и службы → Добавить интеграцию → MQTT. Укажите свой брокер.
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

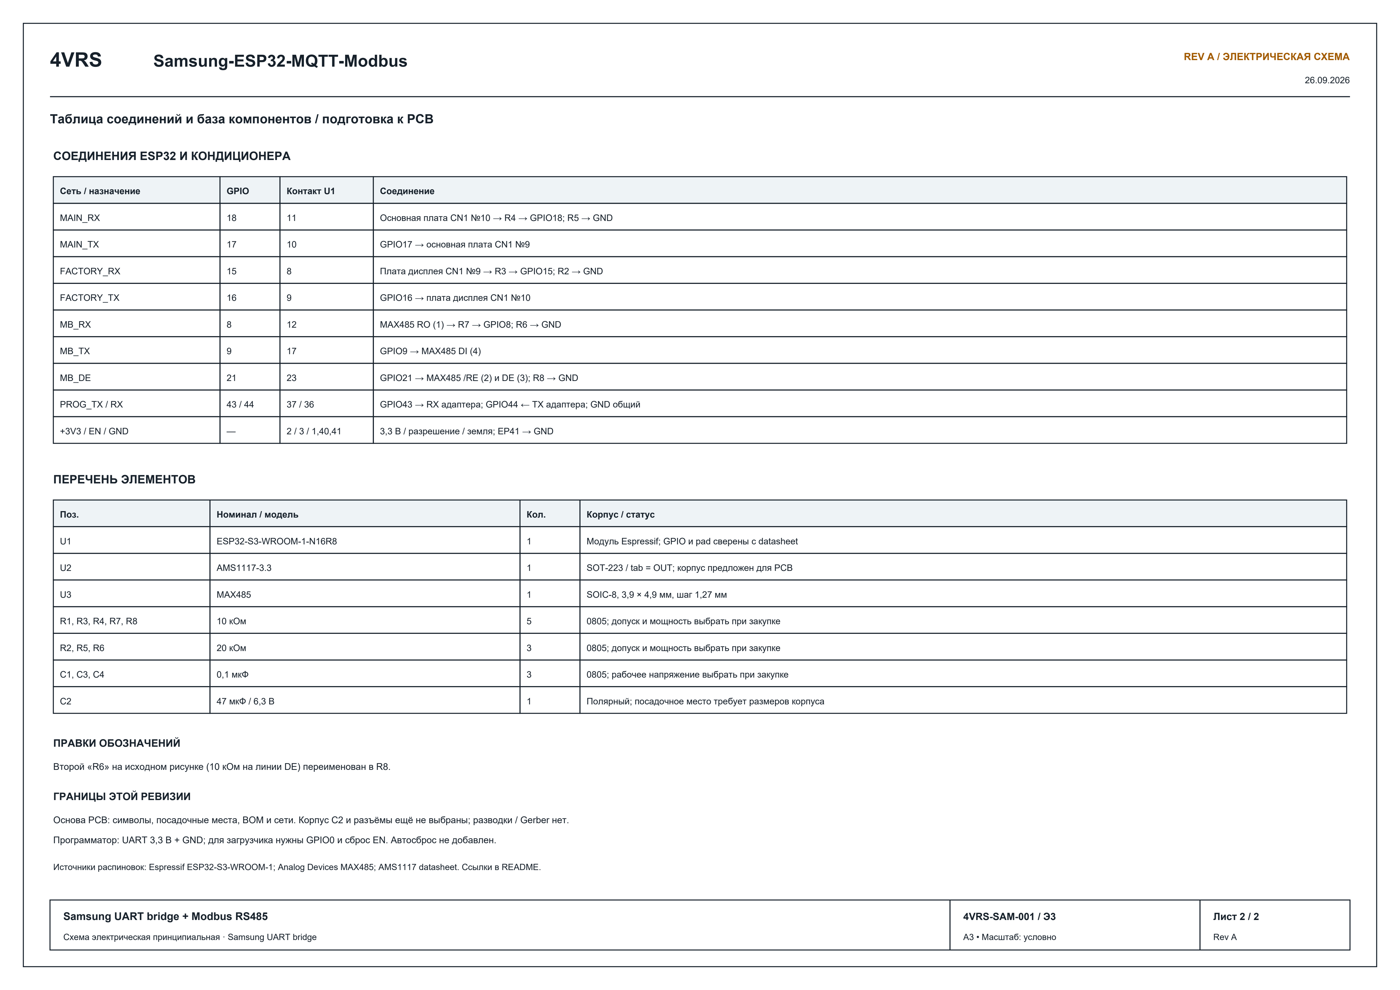
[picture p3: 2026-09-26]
hardware/drawings/preview-2.png

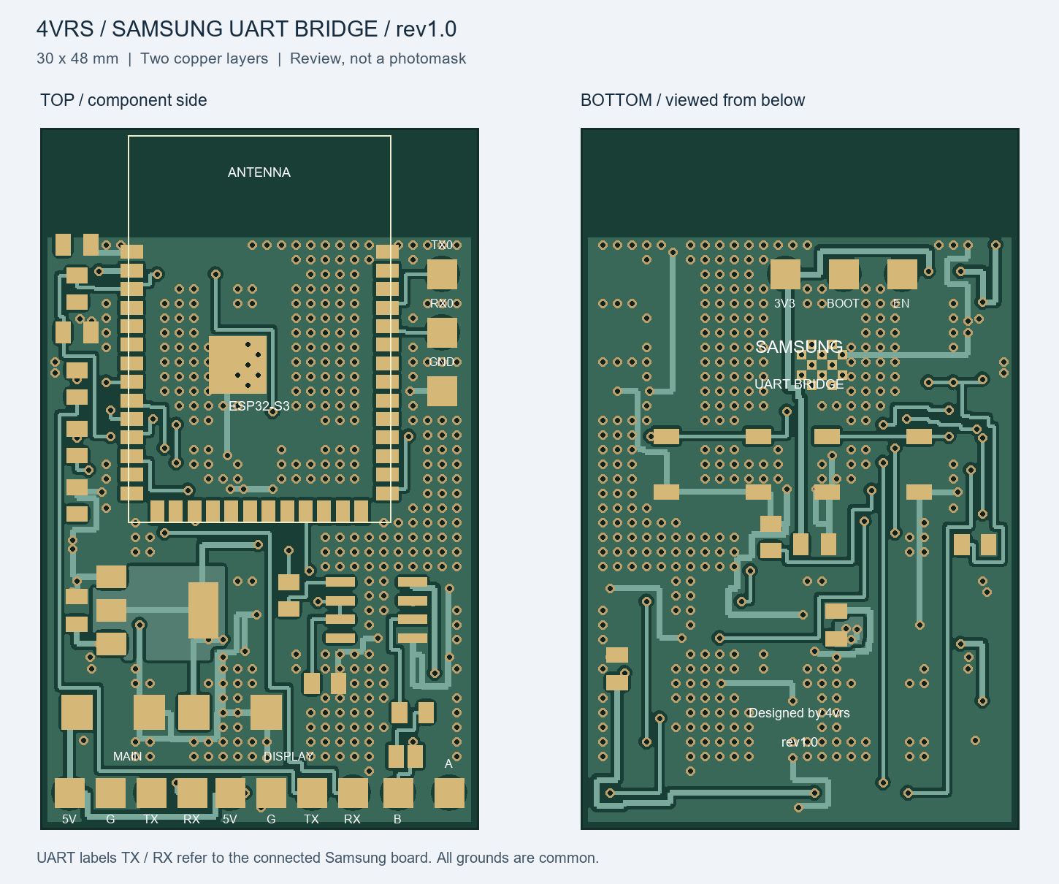
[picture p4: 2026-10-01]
hardware/pcb-rev1.0/review/samsung-both-sides.png

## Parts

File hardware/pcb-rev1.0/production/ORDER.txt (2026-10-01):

samsung-rev1.0
Upload samsung-rev1.0-GERBER.zip. Single board, no panel. Size 30 x 48 mm; 2 copper layers; project thickness 1.0 mm.
Archive contains 7 Gerber layers, PTH Excellon drill and gbrjob. No NPTH holes. Do not mirror. All layers and drills use the same absolute origin.
Repeated DRC: zero violations and zero unconnected items. Outline dimensions and ZIP integrity checked. No assembled hardware validation of this revision yet.

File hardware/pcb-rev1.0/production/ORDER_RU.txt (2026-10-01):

samsung-rev1.0
Для заказа загрузить samsung-rev1.0-GERBER.zip.
Одна плата, не панель. Размер 30 x 48 мм. Два слоя меди. Толщина проекта 1,0 мм.
ZIP содержит 7 Gerber-слоёв, сверловку PTH Excellon и gbrjob; неплакированных отверстий нет.
Не зеркалировать слои. Сверловка и Gerber используют единое абсолютное начало координат.
Повторный DRC: 0 нарушений, 0 несоединённых цепей. Контур и состав архива проверены.
Сборка этой ревизии ещё не прошла аппаратные испытания.

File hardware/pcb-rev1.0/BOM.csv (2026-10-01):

Reference | Value | Footprint | MPN
U1 | ESP32-S3-WROOM-1-N16R8 | RF_Module:ESP32-S3-WROOM-1 | ESP32-S3-WROOM-1-N16R8
U2 | LM1117-3.3 | Package_TO_SOT_SMD:SOT-223-3_TabPin2 | LM1117MP-3.3
U3 | MAX485 | Package_SO:SOIC-8_3.9x4.9mm_P1.27mm | MAX485ESA+
R1 | 10k | Resistor_SMD:R_0805_2012Metric
R2 | 10k | Resistor_SMD:R_0805_2012Metric
R3 | 20k | Resistor_SMD:R_0805_2012Metric
R4 | 10k | Resistor_SMD:R_0805_2012Metric
R5 | 20k | Resistor_SMD:R_0805_2012Metric
R8 | 10k | Resistor_SMD:R_0805_2012Metric
R9 | 20k | Resistor_SMD:R_0805_2012Metric
R6 | 10k | Resistor_SMD:R_0805_2012Metric
R7 | 120 | Resistor_SMD:R_0805_2012Metric
C1 | 220u 10V | Capacitor_Tantalum_SMD:CP_EIA-6032-28_Kemet-C | TAJC227M010RNJ
C3 | 100u 10V | Capacitor_Tantalum_SMD:CP_EIA-6032-28_Kemet-C | TAJC107M010RNJ
C2 | 100n 50V | Capacitor_SMD:C_0805_2012Metric
C4 | 100n 50V | Capacitor_SMD:C_0805_2012Metric
C5 | 100n 50V | Capacitor_SMD:C_0805_2012Metric
C6 | 100n 50V | Capacitor_SMD:C_0805_2012Metric
C7 | 1u 16V | Capacitor_SMD:C_0805_2012Metric
C8 | 10u 10V | Capacitor_SMD:C_0805_2012Metric
SB1 | SB1 | Button_Switch_SMD:SW_SPST_TL3342
SB2 | SB2 | Button_Switch_SMD:SW_SPST_TL3342
JP1 | TERM ENABLE | Jumper:SolderJumper-2_P1.3mm_Open_Pad1.0x1.5mm
TP1 | UART0_TX | TestPoint:TestPoint_Pad_D2.0mm
TP2 | UART0_RX | TestPoint:TestPoint_Pad_D2.0mm
TP3 | GND | TestPoint:TestPoint_Pad_D2.0mm
TP4 | EN | TestPoint:TestPoint_Pad_D2.0mm
TP5 | BOOT | TestPoint:TestPoint_Pad_D2.0mm
TP6 | +3V3 | TestPoint:TestPoint_Pad_D2.0mm
TP7 | A | TestPoint:TestPoint_Pad_D2.0mm
TP8 | B | TestPoint:TestPoint_Pad_D2.0mm
TP9 | +5V | TestPoint:TestPoint_Pad_D2.0mm
TP10 | GND | TestPoint:TestPoint_Pad_D2.0mm
TP11 | MAIN_TX_5V | TestPoint:TestPoint_Pad_D2.0mm
TP12 | H_TX | TestPoint:TestPoint_Pad_D2.0mm
TP13 | +5V | TestPoint:TestPoint_Pad_D2.0mm
TP14 | GND | TestPoint:TestPoint_Pad_D2.0mm
TP15 | FACTORY_TX | TestPoint:TestPoint_Pad_D2.0mm
TP16 | F_TX | TestPoint:TestPoint_Pad_D2.0mm

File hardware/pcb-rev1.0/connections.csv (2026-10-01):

Reference | Pad | Net
C1 | 1 | +5V
C1 | 2 | GND
C2 | 1 | +5V
C2 | 2 | GND
C3 | 1 | +3V3
C3 | 2 | GND
C4 | 1 | +3V3
C4 | 2 | GND
C5 | 1 | +3V3
C5 | 2 | GND
C6 | 1 | +5V
C6 | 2 | GND
C7 | 1 | EN
C7 | 2 | GND
C8 | 1 | +3V3
C8 | 2 | GND
JP1 | 1 | TERM
JP1 | 2 | B
R1 | 1 | +3V3
R1 | 2 | EN
R2 | 1 | MAIN_TX_5V
R2 | 2 | H_RX
R3 | 1 | H_RX
R3 | 2 | GND
R4 | 1 | RO_5V
R4 | 2 | MB_RX
R5 | 1 | MB_RX
R5 | 2 | GND
R6 | 1 | DIR
R6 | 2 | GND
R7 | 1 | A
R7 | 2 | TERM
R8 | 1 | FACTORY_TX
R8 | 2 | F_RX
R9 | 1 | F_RX
R9 | 2 | GND
SB1 | 1 | BOOT
SB1 | 2 | GND
SB2 | 1 | EN
SB2 | 2 | GND
TP1 | 1 | UART0_TX
TP10 | 1 | GND
TP11 | 1 | MAIN_TX_5V
TP12 | 1 | H_TX
TP13 | 1 | +5V
TP14 | 1 | GND
TP15 | 1 | FACTORY_TX
TP16 | 1 | F_TX
TP2 | 1 | UART0_RX
TP3 | 1 | GND
TP4 | 1 | EN
TP5 | 1 | BOOT
TP6 | 1 | +3V3
TP7 | 1 | A
TP8 | 1 | B
TP9 | 1 | +5V
U1 | 1 | GND
U1 | 10 | H_TX
U1 | 11 | H_RX
U1 | 12 | MB_RX
U1 | 17 | MB_TX
U1 | 2 | +3V3
U1 | 23 | DIR
U1 | 27 | BOOT
U1 | 3 | EN
U1 | 36 | UART0_RX
U1 | 37 | UART0_TX
U1 | 40 | GND
U1 | 41 | GND
U1 | 8 | F_RX
U1 | 9 | F_TX
U2 | 1 | GND
U2 | 2 | +3V3
U2 | 3 | +5V
U3 | 1 | RO_5V
U3 | 2 | DIR
U3 | 3 | DIR
U3 | 4 | MB_TX
U3 | 5 | GND
U3 | 6 | A
U3 | 7 | B
U3 | 8 | +5V

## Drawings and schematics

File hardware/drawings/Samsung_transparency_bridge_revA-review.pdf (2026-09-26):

4VRS | Samsung-ESP32-MQTT-Modbus

## Схема электрическая принципиальная

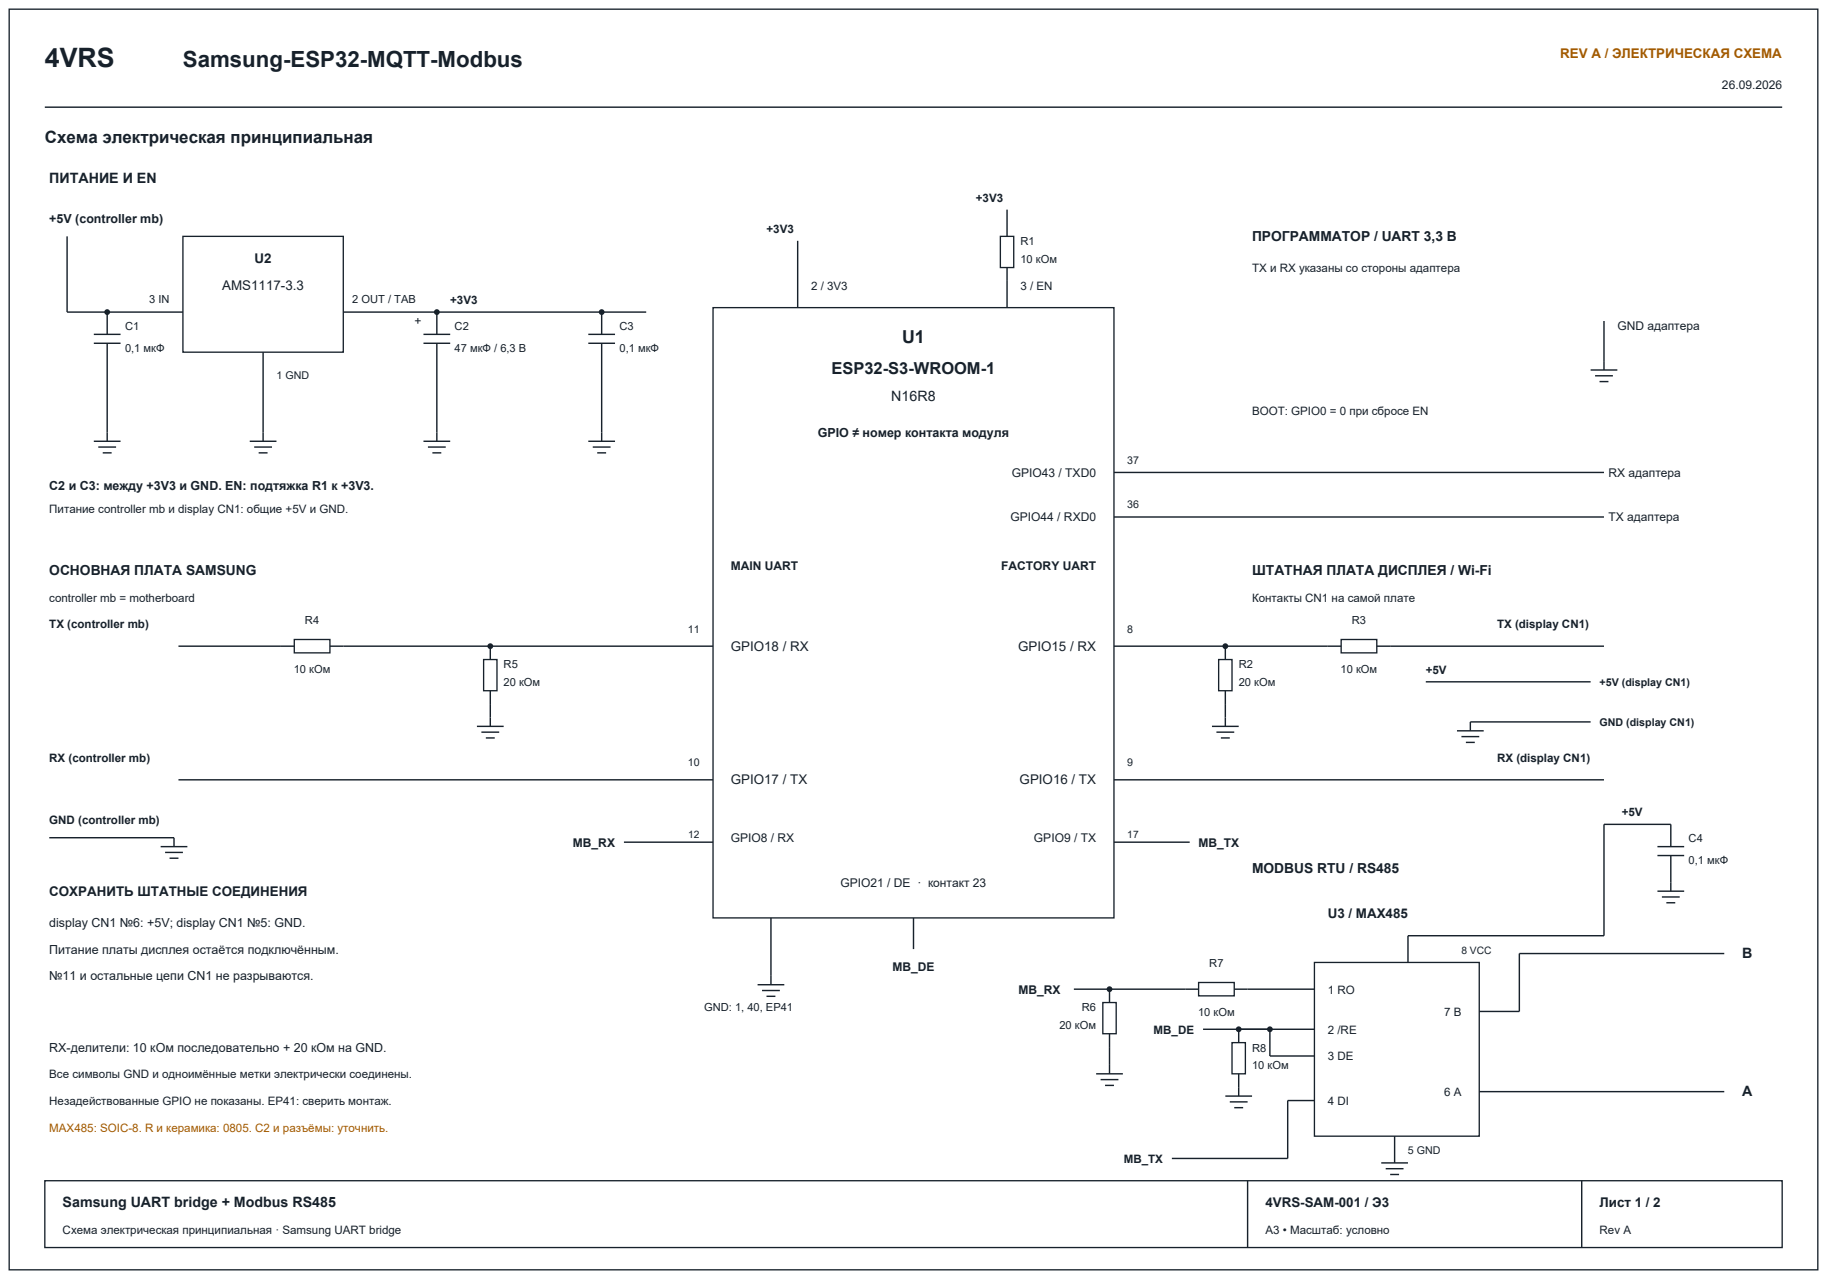
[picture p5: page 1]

TX и RX указаны со стороны адаптера

BOOT: GPIO0 = 0 при сбросе EN

GPIO ≠ номер контакта модуля

C2 и C3: между +3V3 и GND. EN: подтяжка R1 к +3V3.

Питание controller mb и display CN1: общие +5V и GND.

ШТАТНАЯ ПЛАТА ДИСПЛЕЯ / Wi-Fi

Контакты CN1 на самой плате

Питание платы дисплея остаётся подключённым.

№11 и остальные цепи CN1 не разрываются.

RX-делители: 10 кОм последовательно + 20 кОм на GND.

Все символы GND и одноимённые метки электрически соединены.

Незадействованные GPIO не показаны. EP41: сверить монтаж.

MAX485: SOIC-8. R и керамика: 0805. C2 и разъёмы: уточнить.

Samsung UART bridge + Modbus RS485

Схема электрическая принципиальная · Samsung UART bridge

4VRS | Samsung-ESP32-MQTT-Modbus
REV A / ЭЛЕКТРИЧЕСКАЯ СХЕМА

26.09.2026

## Таблица соединений и база компонентов / подготовка к PCB

### Samsung UART bridge + Modbus RS485

Схема электрическая принципиальная · Samsung UART bridge

4VRS-SAM-001 / Э3

A3 • Масштаб: условно

Лист 2 / 2

Rev A

## СОЕДИНЕНИЯ ESP32 И КОНДИЦИОНЕРА

Сеть / назначение | GPIO | Контакт U1 | Соединение
MAIN_RX | 18 | 11 | Основная плата CN1 №10 → R4 → GPIO18; R5 → GND
MAIN_TX | 17 | 10 | GPIO17 → основная плата CN1 №9
FACTORY_RX | 15 | 8 | Плата дисплея CN1 №9 → R3 → GPIO15; R2 → GND
FACTORY_TX | 16 | 9 | GPIO16 → плата дисплея CN1 №10
MB_RX | 8 | 12 | MAX485 RO (1) → R7 → GPIO8; R6 → GND
MB_TX | 9 | 17 | GPIO9 → MAX485 DI (4)
MB_DE | 21 | 23 | GPIO21 → MAX485 /RE (2) и DE (3); R8 → GND
PROG_TX / RX | 43 / 44 | 37 / 36 | GPIO43 → RX адаптера; GPIO44 ← TX адаптера; GND общий
+3V3 / EN / GND | — | 2 / 3 / 1,40,41 | 3,3 В / разрешение / земля; EP41 → GND

## ПЕРЕЧЕНЬ ЭЛЕМЕНТОВ

Поз. | Номинал / модель | Кол. | Корпус / статус
U1 | ESP32-S3-WROOM-1-N16R8 | 1 | Модуль Espressif; GPIO и pad сверены с datasheet
U2 | AMS1117-3.3 | 1 | SOT-223 / tab = OUT; корпус предложен для PCB
U3 | MAX485 | 1 | SOIC-8, 3,9 × 4,9 мм, шаг 1,27 мм
R1, R3, R4, R7, R8 | 10 кОм | 5 | 0805; допуск и мощность выбрать при закупке
R2, R5, R6 | 20 кОм | 3 | 0805; допуск и мощность выбрать при закупке
C1, C3, C4 | 0,1 мкФ | 3 | 0805; рабочее напряжение выбрать при закупке
C2 | 47 мкФ / 6,3 В | 1 | Полярный; посадочное место требует размеров корпуса

ПРАВКИ ОБОЗНАЧЕНИЙ

Второй «R6» на исходном рисунке (10 кОм на линии DE) переименован в R8.

ГРАНИЦЫ ЭТОЙ РЕВИЗИИ

Основа PCB: символы, посадочные места, BOM и сети. Корпус C2 и разъёмы ещё не выбраны; разводки / Gerber нет.

Программатор: UART 3,3 В + GND; для загрузчика нужны GPIO0 и сброс EN. Автосброс не добавлен.

Источники распиновок: Espressif ESP32-S3-WROOM-1; Analog Devices MAX485; AMS1117 datasheet. Ссылки в README.

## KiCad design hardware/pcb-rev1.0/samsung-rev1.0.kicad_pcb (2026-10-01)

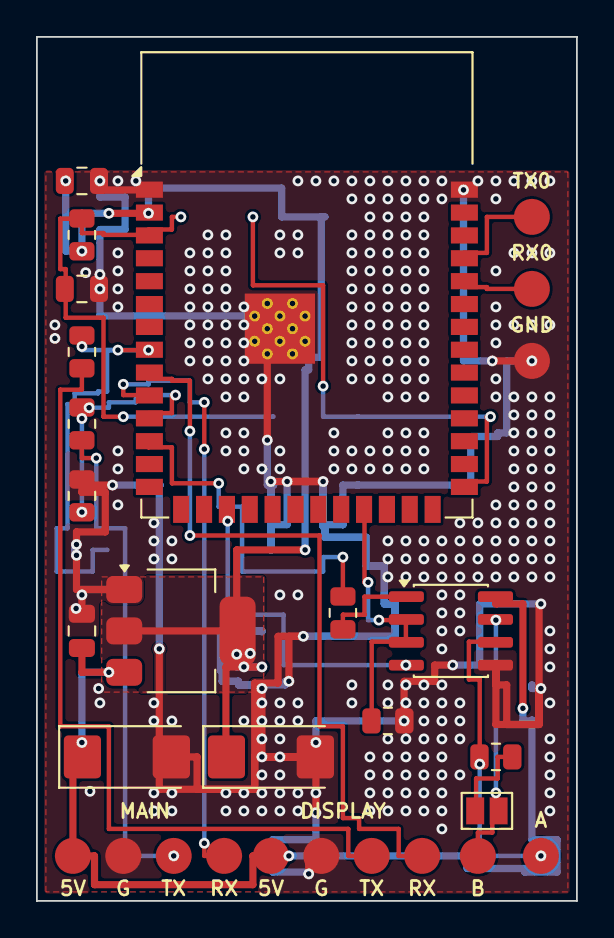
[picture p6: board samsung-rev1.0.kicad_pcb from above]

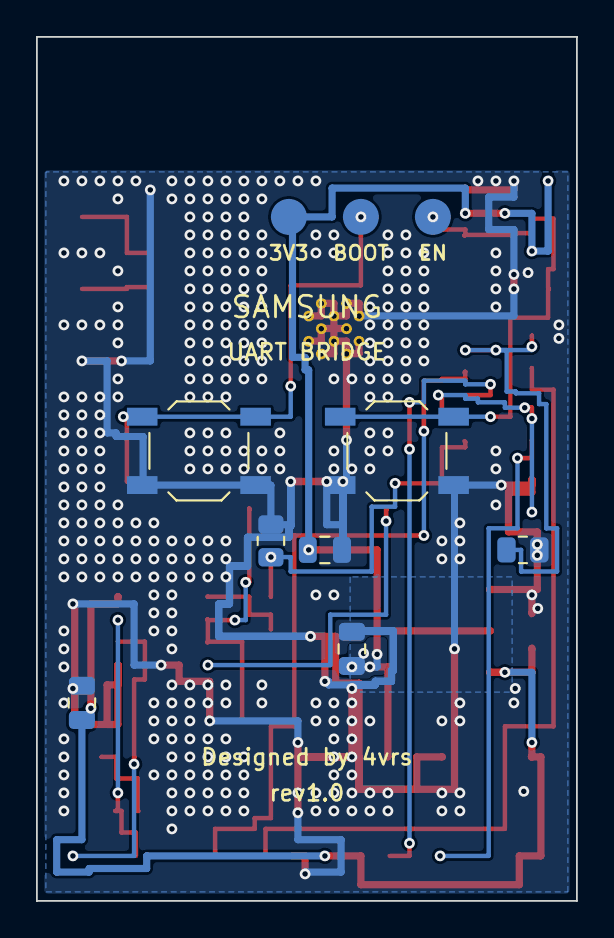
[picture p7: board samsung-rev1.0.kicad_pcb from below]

Board: 2 copper layers, 30.0 x 48.0 mm, 39 parts (10 on the bottom side), 20 nets.

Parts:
C1: 220u 10V; CP_EIA-6032-28_Kemet-C
C2, C4, C5, C6: 100n 50V; C_0805_2012Metric
C3: 100u 10V; CP_EIA-6032-28_Kemet-C
C7: 1u 16V; C_0805_2012Metric
C8: 10u 10V; C_0805_2012Metric
JP1: TERM ENABLE; SolderJumper-2_P1.3mm_Open_Pad1.0x1.5mm
R1, R2, R4, R6, R8: 10k; R_0805_2012Metric
R3, R5, R9: 20k; R_0805_2012Metric
R7: 120; R_0805_2012Metric
SB1: SB1; SW_SPST_TL3342
SB2: SB2; SW_SPST_TL3342
TP1: UART0_TX; TestPoint_Pad_D2.0mm
TP2: UART0_RX; TestPoint_Pad_D2.0mm
TP3, TP10, TP14: GND; TestPoint_Pad_D2.0mm
TP4: EN; TestPoint_Pad_D2.0mm
TP5: BOOT; TestPoint_Pad_D2.0mm
TP6: +3V3; TestPoint_Pad_D2.0mm
TP7: A; TestPoint_Pad_D2.0mm
TP8: B; TestPoint_Pad_D2.0mm
TP9, TP13: +5V; TestPoint_Pad_D2.0mm
TP11: MAIN_TX_5V; TestPoint_Pad_D2.0mm
TP12: H_TX; TestPoint_Pad_D2.0mm
TP15: FACTORY_TX; TestPoint_Pad_D2.0mm
TP16: F_TX; TestPoint_Pad_D2.0mm
U1: ESP32-S3-WROOM-1-N16R8; ESP32-S3-WROOM-1
U2: LM1117-3.3; SOT-223-3_TabPin2
U3: MAX485; SOIC-8_3.9x4.9mm_P1.27mm

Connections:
+3V3: C3.1, C4.1, C5.1, C8.1, R1.1, TP6.1, U1.2, U2.2
+5V: C1.1, C2.1, C6.1, TP9.1, TP13.1, U2.3, U3.8
A: R7.1, TP7.1, U3.6
B: JP1.2, TP8.1, U3.7
BOOT: SB1.1, TP5.1, U1.27
DIR: R6.1, U1.23, U3.2, U3.3
EN: C7.1, R1.2, SB2.1, TP4.1, U1.3
FACTORY_TX: R8.1, TP15.1
F_RX: R8.2, R9.1, U1.8
F_TX: TP16.1, U1.9
GND: C1.2, C2.2, C3.2, C4.2, C5.2, C6.2, C7.2, C8.2, R3.2, R5.2, R6.2, R9.2, SB1.2, SB2.2, TP3.1, TP10.1, TP14.1, U1.1, U1.40, U1.41, U2.1, U3.5
H_RX: R2.2, R3.1, U1.11
H_TX: TP12.1, U1.10
MAIN_TX_5V: R2.1, TP11.1
MB_RX: R4.2, R5.1, U1.12
MB_TX: U1.17, U3.4
RO_5V: R4.1, U3.1
TERM: JP1.1, R7.2
UART0_RX: TP2.1, U1.36
UART0_TX: TP1.1, U1.37

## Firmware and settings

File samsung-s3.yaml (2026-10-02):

substitutions:
  public_release: "false"
  test_update_feed: "false"
  samsung_tx: GPIO17
  samsung_rx: GPIO18
  rs485_tx: GPIO9
  rs485_rx: GPIO8
  rs485_de: GPIO21

esphome:
  name: samsung-s3
  friendly_name: Samsung-ESP32-MQTT-Modbus
  build_path: ../work/build
  project:
    name: fourvrs.samsung_esp32
    version: 1.0.2

esp32:
  board: esp32-s3-devkitc-1
  flash_size: 16MB
  framework:
    type: arduino
psram:
  mode: octal
  speed: 80MHz

external_components:
  - source:
      type: local
      path: components
    components: [samsung_uart, samsung_portal]

logger:
  level: DEBUG
  baud_rate: 0 # All three hardware UARTs serve bridge and Modbus; logs remain on web.

wifi:
  reboot_timeout: 0s
  ap:
    ssid: Samsung-Setup
    password: !secret setup_password
    ap_timeout: 10s
captive_portal:

web_server:
  port: 8080
  version: 3
  local: true
  include_internal: true
  auth:
    username: admin
    password: !secret web_password

ota:
  - platform: esphome
    id: local_ota
    password: !secret ota_password
    on_begin:
      - lambda: id(management).ota_manual(true);
    on_error:
      - lambda: id(management).ota_manual(false);

# MQTT credentials and enable flag are configured in the persistent local portal.
mqtt:
  enable_on_boot: false
  broker: 192.0.2.1
  reboot_timeout: 0s
  topic_prefix: samsung-s3
  discovery: true
  log_topic: null

uart:
  - id: samsung_bus
    tx_pin: ${samsung_tx}
    rx_pin:
      number: ${samsung_rx}
      mode:
        input: true
        pullup: false
        pulldown: false
    baud_rate: 9600
    data_bits: 8
    parity: NONE
    stop_bits: 1
    rx_buffer_size: 4096
    rx_full_threshold: 1
    rx_timeout: 2
  - id: factory_bus
    tx_pin: GPIO16
    rx_pin:
      number: GPIO15
      mode:
        input: true
        pullup: false
        pulldown: false
    baud_rate: 9600
    data_bits: 8
    parity: NONE
    stop_bits: 1
    rx_buffer_size: 4096
    rx_full_threshold: 1
    rx_timeout: 2
  - id: rs485_bus
    tx_pin: ${rs485_tx}
    rx_pin: ${rs485_rx}
    flow_control_pin: ${rs485_de}
    baud_rate: 9600
    data_bits: 8
    parity: EVEN
    stop_bits: 1
    rx_buffer_size: 512
    rx_full_threshold: 1
    rx_timeout: 2

climate:
  - platform: samsung_uart
    id: ac
    name: Air conditioner
    uart_id: samsung_bus
    rs485_uart_id: rs485_bus
    factory_uart_id: factory_bus
    modbus_unit: 1

switch:
  - platform: template
    id: uart_tx_enabled
    name: UART transmission experimental
    entity_category: config
    restore_mode: ALWAYS_ON
    lambda: return id(ac).tx_enabled();
    turn_on_action:
      - lambda: id(ac).enable_tx(true);
    turn_off_action:
      - lambda: id(ac).enable_tx(false);
    # TX enable is intentionally local web only, not replayable by retained MQTT.
    internal: true

  - platform: template
    name: Extended status polling
    entity_category: config
    internal: true
    restore_mode: ALWAYS_OFF
    lambda: return id(ac).extended_poll();
    turn_on_action:
      - lambda: id(ac).set_extended_poll(true);
    turn_off_action:
      - lambda: id(ac).set_extended_poll(false);

button:
  - platform: template
    id: ac_power_on
    name: AC power on
    on_press:
      - lambda: |-
          if (!id(ac).set_power(true)) ESP_LOGW("samsung_power", "ON rejected: UART disabled, busy or stale feedback");
  - platform: template
    id: ac_power_off
    name: AC power off
    on_press:
      - lambda: |-
          if (!id(ac).set_power(false)) ESP_LOGW("samsung_power", "OFF rejected: UART disabled, busy or stale feedback");
  - platform: template
    name: Read Samsung status
    on_press:
      - lambda: id(ac).query();
  - platform: template
    name: Initialize older WiFi UART profile
    entity_category: config
    internal: true
    on_press:
      - lambda: id(ac).initialize_link();

  - platform: template
    name: Read extended Samsung status
    on_press:
      - lambda: id(ac).query_extended();
  - platform: template
    name: Reset filter reminder
    on_press:
      - lambda: |-
          if (!id(ac).submit_extra(4, 0)) ESP_LOGW("samsung_control", "Command rejected: disabled, busy or stale feedback");
  - platform: template
    name: Reset usage counters
    on_press:
      - lambda: |-
          if (!id(ac).submit_extra(6, 1)) ESP_LOGW("samsung_control", "Command rejected: disabled, busy or stale feedback");

binary_sensor:
  - platform: template
    name: AC feedback fresh
    lambda: return id(ac).feedback_fresh();
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

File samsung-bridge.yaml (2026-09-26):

# Experimental inline bridge. Requires four isolated UART wires; see docs/UART_BRIDGE_RU.md.
esphome:
  name: samsung-s3
  friendly_name: Samsung inline UART bridge
  build_path: ../work/build-bridge
  project:
    name: fourvrs.samsung_uart_bridge
    version: 0.4.9-bridge-fan
esp32:
  board: esp32-s3-devkitc-1
  flash_size: 16MB
  framework:
    type: arduino
psram:
  mode: octal
  speed: 80MHz
logger:
  baud_rate: 0
wifi:
  reboot_timeout: 0s
  ap:
    ssid: Samsung-Setup
    password: !secret setup_password
    ap_timeout: 10s
captive_portal:
web_server:
  port: 8080
  local: true
  auth:
    username: admin
    password: !secret web_password
ota:
  - platform: esphome
    password: !secret ota_password
external_components:
  - source:
      type: local
      path: components
    components: [uart_sniffer]
uart:
  - id: sniff_a
    tx_pin: GPIO17
    rx_pin:
      number: GPIO18
      mode:
        input: true
        pullup: false
        pulldown: false
    baud_rate: 9600
    rx_buffer_size: 4096
    rx_full_threshold: 1
    rx_timeout: 2
  - id: sniff_b
    tx_pin: GPIO16
    rx_pin:
      number: GPIO15
      mode:
        input: true
        pullup: false
        pulldown: false
    baud_rate: 9600
    rx_buffer_size: 4096
    rx_full_threshold: 1
    rx_timeout: 2
uart_sniffer:
  id: inline_bridge
  bridge: true
  factory_rx_gpio: 15
  factory_tx_gpio: 16
  rx_a: sniff_a
  rx_b: sniff_b
  password: !secret web_password

switch:
  - platform: template
    name: "UART bridge forwarding"
    optimistic: true
    restore_mode: ALWAYS_ON
    turn_on_action:
      - lambda: id(inline_bridge).set_forwarding(true);
    turn_off_action:
      - lambda: id(inline_bridge).set_forwarding(false);

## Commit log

2026-09-25 Implement Samsung UART control, persistent transports and signed OTA
2026-09-25 Apply MQTT settings through restart and enable UART at boot
2026-09-25 Document complete Modbus Devices integration contract
2026-09-25 Add Wi-Fi status and confirmed network-only reset
    [samsung-s3.yaml]
2026-09-25 Add Samsung web controls and explicit MQTT power commands
2026-09-25 Restore Samsung UART control permission automatically
2026-09-25 Add isolated receive-only dual UART sniffer
2026-09-26 Add experimental bidirectional UART bridge build
2026-09-26 Expose bridge UART and GPIO routing diagnostics
2026-09-26 Add isolated UART loopback diagnostic mode
2026-09-26 Count RX GPIO edges independently of UART decoding
2026-09-26 Initialize RX GPIO explicitly and add guarded read-only UART probe
2026-09-26 Add receive-only diagnostics for both factory-side wires
2026-09-26 Fix Samsung bridge pins at RX15 TX16 and move Modbus to RX8 TX9
    [samsung-bridge-observe.yaml, samsung-bridge-observe9.yaml, samsung-bridge.yaml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]
2026-09-26 Arbitrate one read-only Samsung request through the UART bridge
2026-09-26 Add guarded fan test with preflight and confirmed readback through bridge
2026-09-26 Read ESP32-S3 UART2 clock diagnostics from the correct register bank
    [samsung_uart.cpp]
2026-09-26 Add Samsung electrical schematic and PCB component libraries
    [BOM.csv, connections.csv, external_connections.csv]
2026-09-26 Show electrical schematic directly in project README
2026-09-26 Keep internal experiment notes local and publish current bridge documentation
2026-09-26 Update bridge banner and feature the Samsung Modbus Devices profile
2026-09-27 Move full UART frame diagnostics to MQTT logging topics without HA entities
2026-10-01 Add Samsung PCB rev1.0 KiCad layout and manufacturing files
    [BOM.csv, connections.csv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]
2026-10-01 Replace prototype branding with Samsung product name
    [samsung-s3.yaml, samsung_uart.cpp]
2026-10-02 Add English-default web UI with English/Russian selection for 1.0.1
    [en.tsv]
2026-10-02 Fix bilingual navigation layout and clarify hardware compatibility for 1.0.2
    [samsung-s3.yaml]
